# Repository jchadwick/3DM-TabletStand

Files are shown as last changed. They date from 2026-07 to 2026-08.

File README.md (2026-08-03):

# 3DM Tablet Stand

A 3D-printable, pedestal-mounted holder for a 2024 onn. 8-inch tablet. The holder is intended to slide onto an existing vertical 32 mm OD tube and present the tablet in landscape orientation at a kiosk-like 10 degrees back from vertical (80 degrees above horizontal).

The source tablet mesh and visual references are preserved under [`reference/`](reference/). The always-loaded project rules are in [`AGENTS.md`](AGENTS.md); the active specification, decision history, and validation workflow are indexed in [`docs/`](docs/README.md). The active support-minimized design is generated under [`build/v2/`](build/v2/). Superseded V1 remains available only through Git history at commit `560c6e8`.

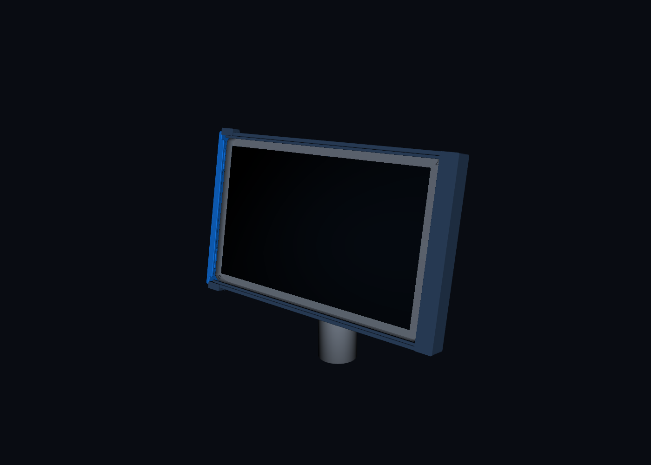
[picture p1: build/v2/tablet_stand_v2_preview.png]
Version 2 tablet stand preview


## Locked design inputs

- Tablet envelope from the supplied OBJ: **200 x 123 x 8.4 mm**.
- Landscape orientation; USB-C is centered on the right short edge as viewed from the screen side.
- Existing support: **32 mm OD vertical tube**.
- Proven printed fit: **32.2 mm ID closed sleeve**, installed by sliding the holder down over the tube end.
- Screen angle: **10 degrees back from vertical / 80 degrees above horizontal**, with the near/bottom edge lower and the far/top edge higher and farther from the user.
- Styling: simple and sleek, with sturdy support but minimal enclosure.
- Retention direction: slide-in edge rails with a screw-free left stop that slides down in a continuous captured dovetail. The groove has a closed internal bottom, with no projecting nub, hook, or detent bump.
- Cable: a slim plug protrudes 0.256 in (6.50 mm) from the tablet; its flat cable section is 0.6 mm thick for roughly 2 in before transitioning to confirmed 3.45 mm round braided cable.
- USB-C handling: the right-angle pigtail turns immediately behind the tablet; its connection and downstream cable stay largely hidden across the open back before entering an open groove/clip on the tube sleeve.

## Repository layout

```text
docs/                 Design decisions and open measurements
docs/README.md        Documentation entrypoint
docs/current-design.md Canonical active design specification
docs/decision-log.md  Chronological record of confirmed and revised decisions
cad/                  Parametric CadQuery source
scripts/              Build validation and direct CAD preview tooling
build/v2/             Active modular STEP, print STLs, parameters, and previews
reference/images/     Uploaded visual references
reference/tablet/     Supplied OBJ and material file
```

## Build the active model

The current project environment uses Python 3.12 with CadQuery 2.8.0. From an environment containing the packages in `requirements.txt`:

```bash
python cad/tablet_stand_v2.py
python scripts/validate_model_v2.py
python scripts/render_cadquery_preview_v2.py
```

## Current status

1. The active model splits the cradle, rear tilt bracket, and sleeve onto support-friendly print datums.
2. Two keyed adhesive joints assemble the main body; print the shared alignment-key STL twice.
3. All active STL files are watertight single solids and preserve the confirmed physical fit dimensions.
4. Exact-production right-side, button, and two-piece left-slide coupons verify the rails, USB-C route, concealed button groove, and screw-free stop fit.
5. Superseded V1 is intentionally absent from the working tree and remains recoverable from Git history.

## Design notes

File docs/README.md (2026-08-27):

# Documentation Guide

Use these documents in this order when resuming work:

1. [`../AGENTS.md`](../AGENTS.md) — always-loaded operating rules and fit-critical context.
2. [`current-design.md`](current-design.md) — the current, actionable specification.
3. [`assembly.md`](assembly.md) — illustrated V3 bracket, sleeve, and tablet assembly instructions.
4. [`decision-log.md`](decision-log.md) — confirmed measurements and decision history.
5. [`validation.md`](validation.md) — required build, validation, and preview checks.
6. [`architecture/decisions/`](architecture/decisions/) — accepted cross-cutting design decisions.
7. [`design-brief.md`](design-brief.md) — original conversation context, source provenance, and open questions.

The `build/v2/README.md` file describes generated artifacts only; it is not the authority for design decisions. Superseded V1 documentation remains in Git history at commit `560c6e8` and is not part of the active workflow.

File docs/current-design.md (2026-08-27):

# Current Design Specification

## Purpose and status

The project is a simple, sleek, FDM-printable landscape holder for a 2024 onn. 8-inch tablet. It mounts permanently to the accessible top end of a vertical 32 mm OD tube. V3 is the active split-cradle design: its physical tongue/receiver coupon fit, the corrected wedge retained and released successfully, and on 2026-08-27 the user reported that all production parts printed well and fit great. V3 preserves the tested tablet, button, USB-C, tube, and cable interfaces while replacing both the 215 mm-wide cradle print and separate left cap with two bed-friendly wings. Permanent adhesive assembly uses the rear tilt bracket between the fixed right wing and sleeve as illustrated in [`assembly.md`](assembly.md). Superseded V1 is archived only in Git history at commit `560c6e8` and is not maintained.

## Orientation and coordinates

The user views the tablet in landscape. The screen faces the user; the bottom long edge is lower and nearer; the top long edge is higher and farther away. The screen is **10 degrees back from vertical**, which is **80 degrees above horizontal**. Do not reintroduce the superseded nearly-flat 10-degrees-above-horizontal interpretation.

In the CadQuery model, X runs left (−) to right/USB-C side (+), Y runs user/bottom (−) to far/top (+), and Z runs up. The tablet plane is rotated +80 degrees about X.

## Fit-critical dimensions

| Feature | Value | Status |
|---|---:|---|
| Tablet envelope | 200 × 123 × 8.4 mm | Measured from supplied OBJ |
| Tablet allowance | 1.0 mm total in X/Y; 0.8 mm in Z | Restored after the zero-nominal Y/Z fit test proved too tight |
| Existing tube | 32.0 mm OD | User measurement |
| Sleeve ID | 32.2 mm | User fit-tested; preserve |
| Sleeve OD / wall | 40.2 mm / 4.0 mm | Active design value |
| Sleeve body / engagement | 50 mm / 51 mm | Active design value |
| Seating cap | 3.0 mm | Deterministic tube stop |
| Sleeve rear offset | 24 mm | Keeps tube out of tablet cavity |
| Sleeve vertical placement | Bottom level with holder's lower long edge (Z = -64.53 mm) | User-requested alignment; rear assembly lowered 14.53 mm |
| V3 center retention | One removable printed tapered cross-wedge through the lower tongue/receiver | No cradle adhesive or screw required; the same 4 × 4 mm channel accepts an M3 bolt, washers, and nut as a fallback after hardware dimensions are confirmed |
| USB-C plug projection | 6.50 mm | User measurement |
| Flat cable thickness / length | 0.6 mm / about 50.8 mm | User measurement |
| Right-angle pigtail reach | 51.4 mm | Marked on user photo; endpoint definition should be confirmed before a close fit |
| Downstream connector body | 9.6 mm marked dimension | User photo; measurement axis/meaning still to confirm |
| Round braided cable diameter | 3.45 mm | User measurement |
| USB-C plug-pocket depth | 8.0 mm clear | 6.50 mm projection plus provisional clearance |
| Rear cable opening | 16 × 12 mm (Y × X): 4 mm inboard + the original full 8 mm outboard span | Photo-requested enlargement adds the green-marked tablet-side area without filling any of the original opening; the plug chamber above remains 8 mm deep |
| Power/volume group | 20–60 mm from landscape top-left; 2 mm wide across tablet thickness; centered; 1 mm edge protrusion | User measurements |
| Top button channel | Concealed internal groove, 2 mm high × 1.2 mm deep; active V3 span X = −103.5 mm to the center seam, with 0.2 mm cutter overrun | Clears the 1 mm button projection over the complete removable left-wing slide path while preserving a solid 1.8 mm exterior rail wall, retaining perimeter, and closed left outer wall |
| Rear bracket cable clip/channel | One 12 mm-long open C-channel, X = 25–37 mm; 4.15 mm ID / 2.8 mm snap opening | Replaces two 6 mm clips; removes the inaccessible inner X = 16 mm clip while preserving total cable contact length and clearing the center gusset |
| Braided-cable sleeve channel | 4.15 mm ID / 2.8 mm snap opening | 0.70 mm total clearance around confirmed cable diameter |
| Sleeve channel embed / remaining wall | 1.2 mm / 2.8 mm minimum | Keeps the 32.2 mm tube bore intact |
| Exposed finish | Rear frame opening follows the tablet's approximately 7.0 mm plan corner radius; outer rear-frame radius is 28.0 mm. One continuous screen-facing ring now supplies all four visible rails/closures and is interrupted only by the flush 0.35 mm wing split—there are no stacked lips, end caps, bezel overlays, or coplanar shroud faces. Its opening remains 196.6 × 119.6 mm with 5.3 mm tablet-concentric corners and 1.7 mm overlap. V3 keeps 1.45 mm rail/wall, 1.05 mm lip, and 1.70 mm left-closure plan corners, with 1.30 mm front/exposed rail/wall fillets and 0.90 mm ring fillets; rear print datums remain flat | Removes visible ridges and superseded slider/end-stop remnants while preserving the approved screen edge, cavity fit, insertion path, and rear-face-down layout |
| V2 main-body split | Cradle, rear tilt bracket, sleeve | Separates conflicting print axes |
| Structural glue alignment | 35 × 15 × 1.8 mm cross key, print quantity 1 | Used only for the unchanged rear-bracket-to-sleeve bond; the bracket bonds to the fixed right wing without a cradle key, and the removable left wing receives no adhesive |
| Cradle-to-bracket bond | 74 × 36 mm nominal mating face | Align matching side and top edges |
| Bracket-to-sleeve bond | 60 × 28 mm nominal mating face | Align matching side and front edges |
| V2 left cap (historical) | Horizontal local +X insertion on two enlarged tapered rail-end plugs | Physically fit well, but the entire separate-cap scheme is superseded by the integral V3 left wing |
| V3 cradle split | Left wing 125.00 × 139.00 × 14.20 mm; right wing 111.33 × 139.00 × 14.20 mm | Replaces the 215 mm-wide single cradle print; the one-piece front ring and buried rear shrouds absorb the outer joiner blocks without visible ridges; both wings remain rear-face-down and fit comfortably on the 220 mm bed |
| V3 removable joint | Three integral +X tongues: one at each long rail and one through the center plate; 18 mm seated insertion | Physical coupon fit despite major adhesion/stringing defects; retain the matching receiver's 0.50 mm total root and 1.10 mm total tip/lead clearances |
| V3 locking wedge | One corrected printed 3.70-to-3.30 mm tapered cross-wedge with a 7 mm pull head | Corrected pin retained and released successfully in the physical coupon; original floating-body G-code is stale; channel can take an M3 bolt if necessary |
| V3 left edge | Fully enclosed, rounded, integral part of the left cradle wing | No separate cap, plugs, sockets, screw, or nub; the left wing itself closes the holder during two-piece tablet assembly |
| Right fit coupon | Exact X = 78.0–111.5 mm crop of V2 cradle | 33.5 × 130 mm plan envelope; tests restored rail fit, right-edge seating, USB-C pocket, and open 16 × 8 mm cable rectangle |
| Button fit coupon | Exact top-left production-rail crop | 73.5 × 11 × 14.8 mm envelope; tests insertion path, seated button clearance, and intact wall after relief |
| Twin-plug coupon (historical) | Exact V2 crops of one rail socket and its identical tapered plug | Physically passed and remains useful process evidence; the joint is absent from V3 |

## Functional design

- The V3 candidate is assembled from two flat-print cradle wings, one removable locking wedge, a rear tilt bracket, and a closed sleeve. There is no separate left end cap and no cradle adhesive. The structural alignment-key STL is printed once for the unchanged bracket-to-sleeve glue joint.
- The left wing has a continuous rounded wall with no separate cap or visible entry step. The obsolete 4 mm V2 end-stop rail lead is closed; each long rail overlaps the integral closure by 0.20 mm behind the visible face. One screen-facing ring spans the complete 139 mm envelope and both wings, leaving only the flush center split. The right wing retains the tested USB-C housing. Its rear-floor opening keeps the complete original 8 mm outboard span and adds 4 mm inboard: the 16 × 12 mm opening runs from X = 96.5–108.5 mm across the fitted tablet edge at X = 100.5 mm. All V2 cap-specific tapered plugs, sockets, receiver bulges, lip overlays, and slider-looking remnants are absent from V3.
- To load the tablet, seat its USB-C/right edge in the fixed right wing, align the fully enclosed left wing, and slide it +X until all three tongues reach their closed socket seats. Push the tapered wedge through the lower transverse channel. To service the tablet, pull the wedge and slide the left wing back off.
- The two outer tongues are 6 mm tall, bed-supported blocks entering locally reinforced receivers with open bed-side floors and softened exterior edges. Their 4.5 mm maximum socket roofs stay below the confirmed 10 mm PLA bridge rule. The center tongue remains within the 3 mm rear plate and enters a through-depth planar pocket.
- The lower tongue and receiver share a 4 × 4 mm transverse channel. The printed wedge narrows from 3.70 to 3.30 mm for a forgiving lead and snug seated root. If the actual PLA wedge is unreliable, the channel clears an M3 shaft; exact head, washer, nut, and length still require the user's hardware measurements.
- The rear bracket is bonded only to the fixed right wing and the bracket-to-sleeve joint remains glued. The bracket may contact the removable left wing but must receive no adhesive there. This preserves tablet serviceability while the existing 74 × 36 mm plate helps resist out-of-plane movement at the seam.
- The cradle prints with its complete rear frame datum on the bed. The cable clip/channel is on the rear bracket. The previous end-stop screw boss and pilot are removed.
- The rear bracket's 74 × 36 mm tilted plate bonds to the matching upper region of the cradle center plate. The active V3 production STL prints on that broad bond plate with its open cable channel facing upward; this supersedes the old V2 foot-down production orientation for the replacement bracket.
- The sleeve prints upside down on a 60 × 46 mm flange. Its tube-entry bore therefore remains open upward and its 3 mm seating cap becomes a supported floor rather than a 32.2 mm bridge.
- The rear bracket bonds only to the right cradle wing, using its existing broad face without a cradle alignment key. The bracket-to-sleeve bond retains one loose-fit 35 × 15 × 1.8 mm cross key and the previously validated groove clearance. Adhesive must be selected and prepared for the actual filament, but no adhesive belongs on the removable left wing or tongue/socket joint.
- The holder slides down over the tube using the unchanged closed cylindrical sleeve with a solid seating cap.
- The complete rear sleeve/collet assembly is lowered so its bottom is level with the installed holder's lower long edge. The sleeve dimensions and proven tube fit are unchanged.
- Two rear gussets connect the rear-offset sleeve to the tablet back support.
- The tablet is loaded between the two cradle wings before the wedge is inserted. The integral left wing closes the left edge; no separate cap is printed or installed, and the wing remains removable.
- The landscape-top rail has a concealed 2 mm-high × 1.2 mm-deep groove in its inner face, centered on the tablet's thickness. In active V3 it runs continuously from the integral closure-side rail interior at X = −103.5 mm to the center seam, with only a 0.20 mm cutter overrun past the split for a clean edge. This clears the buttons during the entire +X left-wing slide, not only at their seated position. The groove does not cut the left outer closure or exterior face: a solid 1.8 mm outer wall and the complete screen-facing ring remain.
- The single continuous screen-facing ring covers the right side from the tablet edge to the solid outer wall; two internal stop walls beneath it locate the tablet while accommodating the 6.50 mm-projecting USB-C plug. The ring remains structurally continuous because the cable opening is in the rear pocket floor, not through the visible face.
- The right-angle adapter turns immediately around the tablet's right edge and onto the open back; the flat pigtail and its downstream connection should be largely hidden behind the tablet rather than leaving straight out through the right wall.
- The right side presents a continuous enclosed screen-facing face: the outer wall and full-depth cap span the complete 139 mm V3 perimeter, including the extended top/bottom corners. The plug chamber remains open toward the tablet cavity and keeps its full 8 mm depth above the rear floor for the recorded 6.50 mm projection. The rear-floor opening is enlarged from its original 16 × 8 mm area by adding the green-marked 4 mm inboard relief, producing a 16 × 12 mm opening. None of the original outboard opening is filled or removed.
- The 3.45 mm braided section snaps into one 12 mm-long open C-channel on the rear bracket. The channel spans X = 25–37 mm in the former outer-clip region; the crowded inner X = 16 mm clip is removed. From the channel it drops through open space outside the right gusset, sweeps behind the sleeve, and enters the rear-facing external sleeve channel through its snap opening. No segment passes through a holder, gusset, or sleeve solid, and the 9.6 mm-marked connector body remains accessible outside all captive features.
- The external sleeve channel has 4.15 mm internal clearance and a 2.8 mm snap opening. Its shallow 1.2 mm embed leaves at least 2.8 mm of the original 4 mm sleeve wall and does not intersect the tested 32.2 mm bore.
- The rear frame opening follows the supplied tablet mesh's approximately 7 mm corner curve, and the outer rear-frame plan radius remains 28 mm. The visible front is now authored as one asymmetric ring rather than a union of separately pre-filleted V2 lips, left/right caps, corner infills, and full-height shrouds. It keeps the established 1.70 mm outer short-edge plan corner and 0.90 mm cross-sectional fillet while cutting the same sharp-edged 196.6 × 119.6 mm opening with 5.3 mm corners and 1.7 mm tablet overlap. The 1.30 mm long-wall and short-wall finish remains on exposed/front edges; the rear-side wall edges stay flat where required for a complete watertight print datum. Two rear shrouds stop 0.70 mm below the front face and fuse inside the ring, hiding joiner blocks without a coplanar ridge. The left and right wing colors meet only at the unavoidable 0.35 mm center split, and V3 has no end-stop, slider, cap, or screw-era surface remnant.
- Keep the rear open for material efficiency, airflow, and access. Do not convert this to a full bezel without confirming all device clearance zones.
- Active shared geometry is in `cad/tablet_stand_core.py`; the tested unsplit geometry remains in `cad/tablet_stand_v2.py`, and `cad/tablet_stand_v3.py` owns the removable tongue/wedge split, V3 assembly, and exports. Generated V3 review outputs are under `build/v3/`. If the V3 physical joint coupon passes, promote V3 to the sole production path and archive the V2-only workflow rather than maintaining both indefinitely.
- Before another full right wing, print or otherwise physically verify the revised right-side USB region rear-face down in the intended PLA process. Slide the tablet's right edge through the production rails, seat it against the internal stops, connect the real USB-C adapter, and confirm that the complete thick cable section turns through the enlarged 16 × 12 mm rear rectangle without pinching or forcing the tablet. The prior physical wing proves tablet fit, not this enlarged floor opening.
- Also print `tablet_stand_v2_button_fit_coupon.stl` rear-face down. Slide it along the tablet's landscape-top edge from the left and confirm that the button group passes freely through the concealed inner groove without being pressed, while the outside of the rail remains closed and smooth.
- The first `tablet_stand_v3_lock_coupon_all3.stl` print physically passed tongue/receiver fit despite severe adhesion and stringing. The corrected pin then retained and released successfully. Do not rescale or change the confirmed tongue/socket clearances. The stale combined coupon G-code and pre-finish right-wing slices remain recoverable from Git history. The prior right-wing production job used snug 45° supports and a 5 mm brim and completed on 2026-08-10; on 2026-08-27 the user reported that all current production parts printed well and fit great.

## Current print status

- The replacement rear bracket uses one 12 mm outer cable channel and the active V3 broad-plate-down, channel-up orientation. Its functional PLA slice uses 0.20 mm layers, five walls, 40% grid infill, no supports, and no brim; validation passed at 7.5 mm³/s peak flow with an estimated 1 h 31 m / 22.4 g.
- The user explicitly authorized the print. A fresh full-bed camera snapshot showed an empty plate, and Moonraker accepted the job at 2026-08-27 04:48:05 UTC. Completion and physical cable insertion remain to be confirmed.

## Full-cradle slice status

- The unsplit V2 cradle is 215 × 135.6 × 14.8 mm and technically fits the confirmed 220 × 220 mm bed, but its narrow margin motivated the V3 split.
- The V3 left and right cradle-wing STLs are each single watertight solids and remain rear-face-down. Their largest plan dimension is 139 mm, leaving generous bed margin.
- Previous full-cradle, end-stop, and combined V3 coupon G-code files are stale for the current geometry; Git history retains them as process evidence. The tongue/receiver fit and wedge retention gates passed. The corrected full-span right-wing job completed from prior geometry using rear-face-down, 0.16 mm layers, 3 walls, 20% grid infill, 55° snug build-plate-only supports, a 0.24 mm Z gap, 0.70 mm XY gap, 3 interface layers, and a 5 mm brim. That print was very stringy, but the tablet slid in smoothly and fit snugly. On 2026-08-27 the user subsequently confirmed that all current production parts printed well and fit great. Preserve the active cavity and joint dimensions for any reprint.

## Known unknowns before a full print

- Flat cable and connector-body width.
- Whether the photo's 9.6 mm annotation is connector width, height, or another measurement.
- Speaker, camera, microphone, and any other edge clearances not covered by the measured power/volume group.
- The successful V2 twin-plug coupon remains useful PLA fit evidence, but it does not replace the required V3 tongue/wedge coupon test.
- Unobstructed tube length above its existing mounting point.
- The Ender-3 Pro profile, 0.4 mm nozzle, PLA, 220 × 220 × 250 mm build volume, and rear-face-down cradle orientation are verified. The tongue/receiver physically fit on 2026-08-10 despite major adhesion/stringing defects, and the corrected wedge retained and released successfully. Full production slices and first-layer adhesion strategy remain to be reviewed.
- Adhesive selection, surface preparation, clamp method, and cure time for the selected filament.

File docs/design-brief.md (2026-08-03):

# Tablet Stand Design Brief

## Goal

Create a simple, sleek, sturdy FDM-printable holder for a 2024 onn. 8-inch tablet. The assembly will live permanently on top of a vertical 32 mm OD tube. The tablet should be securely retained without a bulky enclosure or unnecessary obstruction of its surfaces.

## Supplied references

- `reference/tablet/tinker.obj`: Tinkercad export of the tablet, with a measured axis-aligned envelope of 200 x 123 x 8.4 mm.
- `reference/tablet/obj.mtl`: material definition accompanying the tablet OBJ.
- `reference/images/slim-usb-c-cable.png`: visual reference for the low-profile USB-C lead.
- `reference/images/tilt-reference.png`: an early side-view sketch retained as source history; its 10-degrees-above-horizontal interpretation is superseded by the kiosk-angle correction below.

Source file SHA-256 checksums:

```text
2c9b8806e64e52a87e7ebacec791b912b9a4fb774c618ab4b1893b57f28cefe8  tinker.obj
fcf8ac13a37b9b38b3052e32e8f2407ed103fb5f62b3468fe42578f922007f8b  obj.mtl
575f7f808ad992e87ae410be5e9742a2c2b65725099cb73130cf4a423226180e  slim-usb-c-cable.png
de3a6b13c21a19f52a0c6697288e47ec1d9f3da20c9b4bcc9ad1b73e86abc622  tilt-reference.png
```

## Geometry and orientation

- Tablet nominal envelope: 200 mm wide, 123 mm deep, and 8.4 mm thick.
- The tablet is landscape when seen by the user.
- The bottom long edge is closest to the user and lower.
- The top long edge is farther from the user and higher.
- The screen plane is **10 degrees back from vertical**, equivalently **80 degrees above horizontal**, and faces the user like a kiosk.
- The top long edge is farther from the user and higher; the bottom long edge is nearer and lower.
- Across the 123 mm tablet depth, an 80-degree rise produces approximately 121.1 mm of vertical elevation and 21.4 mm of horizontal setback between the long edges.
- The USB-C connection is at the midpoint of the right 123 mm edge when viewed from the screen side.

## Pedestal interface

- The existing tube is vertical with a 32 mm outside diameter.
- A previously test-printed cylinder with a 32.2 mm inside diameter fits the tube tightly; preserve that functional ID.
- The stand should use a closed sleeve and install by sliding straight down over the accessible tube end.
- Because the tablet is nearly vertical, the sleeve must sit behind the screen plane rather than intersecting it. Version 1 offsets the sleeve axis 24 mm behind the tablet plane and ties it to the central back support with two ribs.

## Tablet support and retention

Concepts considered:

- **Open gravity tray:** easiest to print and least obstructive, but not secure enough against bumps or lifting.
- **Flexible snap clips:** compact and removable, but rejected because stronger retention is wanted and the printer/filament do not produce consistently tight tolerances.
- **Full screw-together bezel:** very secure, but uses more material, obstructs more of the tablet, and requires detailed cutouts for buttons, speakers, cameras, and screen margins.
- **Selected direction — slide-in rails with one-screw end stop:** narrow fixed rails overlap only the tablet's outer bezel. The tablet slides into a deliberately forgiving channel, and a removable stop secured by one M3 screw blocks the insertion edge. Soft foam or felt can remove rattle and protect the tablet without relying on a precision printed fit.

The selected direction should keep the rear largely open for airflow and material efficiency. Edge rails and the end stop must avoid the USB-C connection and should not cover unknown button, camera, or speaker locations until those locations are verified.

## USB-C routing

- Port location: center of the tablet's right short edge.
- Flat cable section: 0.6 mm thick for approximately 2 in (50.8 mm).
- Plug projection from tablet: 0.256 in (6.50 mm).
- The original width value remains ambiguous, so the first design should use a generous plug chamber and cable groove rather than a close-fitting captive tunnel.
- The right-angle adapter turns immediately behind the tablet. Its photo-marked 51.4 mm pigtail and downstream connection should stay behind the open back, then route to an open groove/clip on the sleeve or collet before exiting near the tube.
- The downstream cable is confirmed as 3.45 mm diameter round braided wire. Version 1 gives it a 4.15 mm open snap channel on the rear of the sleeve and preserves at least 2.8 mm of sleeve wall over the tested bore.
- Any turn in the cable route should be broad and radiused. The printed holder must not clamp the thin flat section, force a sharp bend at the connector, require the larger downstream connector to pass through a captive tunnel, or cut into the tested 32.2 mm sleeve bore.

## First concept intent

- A lightweight skeletal back support with narrow perimeter rails.
- A removable end stop retained by one M3 screw.
- A vertical 32.2 mm ID sleeve centered left-to-right and offset behind the tablet plane.
- Low-profile gussets blending the sleeve into the back support.
- A right-edge USB-C pocket that lets the right-angle pigtail turn behind the tablet, plus a largely hidden and serviceable rear route to the tube sleeve.
- Rounded exterior edges and a visually quiet, symmetric form except where the cable route requires asymmetry.

## Measurements to validate before final print

- Flat cable and connector body width.
- The meaning/axis of the photo-marked 9.6 mm connector dimension.
- Exact locations of power/volume buttons, speakers, cameras, and microphones near any retaining rail.
- Desired sleeve engagement length and available unobstructed tube length.
- M3 screw length and whether a nut, heat-set insert, or tapped plastic hole will be used.
- Printer nozzle, layer height, build volume, filament type, and preferred print orientation.
- Fit allowance around the tablet, ideally checked with a small rail-and-stop test coupon before printing the full holder.

## Version 1 implementation

The first parametric concept, now archived at Git commit `560c6e8`, used a 1.0 mm total allowance in X and Y and 0.8 mm in Z, narrow U-shaped rails on the near and far long edges, internal right corner stops behind a closed USB-C plug housing, and a full-height removable left end stop with an M3 clearance hole. Its measurements that survived physical testing were promoted into the active V2 core; the superseded model itself is not maintained.

With the corrected kiosk orientation and closed cable end, the installed main-body envelope is approximately 216.0 x 66.42 x 130.49 mm. Both exported STL parts are single watertight solids. Version 1 is a form and fit concept—not yet a production-ready print—and should be revised after checking the physical tablet's controls and testing a small fit coupon.

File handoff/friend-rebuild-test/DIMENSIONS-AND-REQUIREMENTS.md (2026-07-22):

# Dimensions and requirements

This sheet consolidates only the user's words, measurements, and supplied reference assets. It does not use or describe the existing stand CAD.

## Tablet

| Item | Value / requirement | Basis |
|---|---:|---|
| Device | 2024 onn. 8-inch tablet | User prompt |
| Supplied reference envelope | 200 × 123 × 8.4 mm | Direct min/max measurement of vertices in `assets/tinker.obj` |
| Intended orientation | Landscape | Right-hand short-edge USB-C placement and supplied tablet envelope |
| USB-C location | Center of the right-hand side/short edge when facing the screen | User prompt |
| Final screen angle | 10° back from vertical; equivalently 80° above horizontal | Later user correction; supersedes the early 10°-above-horizontal interpretation |
| Direction of lean | Bottom long edge is closer to the user; top long edge is farther from the user | User clarification |

The OBJ is a device envelope/reference mesh, not a printable stand design. Its raw bounds are X = −93 to 107 mm, Y = −72 to 51 mm, and Z = 0 to 8.4 mm.

## Existing support tube

| Item | Value / requirement | Basis |
|---|---:|---|
| Tube outside diameter | 32.0 mm OD | User measurement |
| Tested mating bore | 32.2 mm ID | User fit test; described as perfectly tight |
| Mounting concept | Stand sits permanently on top of the tube | User prompt |

Do not substitute a generic fit allowance for the 32.2 mm bore without discussing it: that dimension comes from a physical test print on the actual tube.

## USB-C cable and adapter

| Item | Value / requirement | Confidence / note |
|---|---:|---|
| Plug/adapter projection from tablet | 0.256 in = 6.5024 mm | Later prompt explicitly uses an inch mark. The first prompt says `0.256mm`, which conflicts and appears to be a unit typo. Preserve the discrepancy until physically checked. |
| Flat section description | Flat, very low profile | Explicit user description |
| Flat-section transverse measurement | First prompt says `.7mm wide`; prior planning also treated the flat section as about 0.6 mm thick | Measurement axis and exact value should be rechecked before making a close fit |
| Annotated flat pigtail length | 51.4 mm | Handwritten marking in `assets/IMG_7233 Large.jpeg` |
| Annotated downstream connector-body measurement | 9.6 mm | Handwritten marking in the physical photo; the measurement axis is not unambiguous |
| Additional handwritten mark | `2` near the downstream connector body | Units and axis are not sufficiently clear to use as a captive-feature dimension |
| Cable after pictured pigtail | 3.45 mm diameter, round braided wire | Explicit later user measurement |

Cable routing requirements:

- The right-angle USB-C adapter turns immediately behind the tablet.
- The adapter/pigtail should be largely hidden and routed toward a groove in or on the tube collet/sleeve area.
- The tablet should be able to slide into the holder. It is acceptable to plug in the cable first and then slide the tablet into place.
- Keep cable routing open or snap-in. Both ends have USB-C connectors, so do not require a connector to pass through a small captive hole.
- Clips are acceptable and desired; the free cable path must not pass through solid material to reach them.
- The downstream connector body should remain outside close-fitting captive features until its 9.6 mm annotation axis and other body dimensions are confirmed.

## Holder behavior and appearance

- Simple and sleek.
- Sturdy, but do not enclose or “suffocate” the tablet unnecessarily.
- A front bezel is optional; a stable tray or partial wrap is acceptable.
- Retention should be more secure than an occasional snap-out arrangement.
- Outside corners should be lightly rounded/filleted so they are not sharp.
- The right side should be solid and fully enclosed in the front/oblique view, not partially exposing the tablet edge or recessed USB-C pocket; it must still accommodate the USB-C connection and rearward cable turn while supporting slide-in tablet installation.

## Measurements still needed before a close-fitting final design

- Confirm the flat cable's width and thickness axes; reconcile 0.7 mm versus approximately 0.6 mm.
- Confirm the 9.6 mm and `2` markings on the downstream connector body, including axis and units.
- Confirm tablet button, speaker, camera, and microphone locations relative to any rail, bezel, or stop.
- Confirm available tube engagement length.
- Confirm printer, nozzle, material, build volume, and intended print orientation.

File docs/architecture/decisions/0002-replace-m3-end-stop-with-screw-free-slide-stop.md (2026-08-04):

# ADR-0002: Replace M3 end stop with screw-free slide stop

- Status: superseded
- Date: 2026-08-02
- Deciders: Project maintainers
- Supersedes: ADR-0001
- Superseded by: ADR-0003

## Context

ADR-0001 established the support-minimized four-module V2 layout but retained
one M3 screw for the removable left tablet stop. The user rejected that visible
fastener and requested a left edge that installs by sliding downward and remains
removable through a guided fit or optionally permanent with a small amount of
adhesive. After reviewing the first screw-free implementation, the user also
rejected its projecting landing nub, rear hooks, and detent bumps in favor of a
sleek tongue-and-groove joint. The stop must still print separately,
must not collide with either long rail during insertion, and must preserve the
cradle's broad rear print datum. The user also requested softer exposed edges.

## Decision

Retain ADR-0001's cradle, rear-bracket, sleeve, alignment-key, and print-layout
decisions, but replace the M3-mounted end stop with a screw-free top-down slide
stop. Use one continuous captured dovetail: the production cradle receives a
closed-bottom groove and the separate stop receives a matching undersized tongue.
The narrow groove mouth captures the wider tongue head; the internal closed
bottom establishes the seated position. Do not add rear hooks, detent bumps, or
an external lower landing. Adhesive is optional.

Use an exact two-piece production crop to physically test the slide clearance,
dovetail capture, and closed-bottom seating before the revised full cradle is printed.
Soften exposed perimeter, rail, lip, and stop edges with the active fillet radii
without changing the confirmed tablet-cavity allowances.

## Consequences

### Positive

- Eliminates the only visible mechanical fastener and its unconfirmed screw
  length and pilot strategy.
- The stop remains independently replaceable and can be glued only if desired.
- The closed-bottom groove gives a deterministic seated position while the
  dovetail prevents the stop from peeling away from the cradle.
- Removing the external landing, hooks, and bumps restores a clean rounded
  lower-left silhouette and the cradle's 215 × 130 mm envelope.
- Rounded longitudinal edges make the printed holder less sharp in hand.

### Negative

- The friction fit is printer- and material-dependent and requires a physical
  PLA coupon before the full cradle.
- The long, enclosed sliding surfaces remain sensitive to printed PLA clearance
  and must be physically tested before committing to the full cradle.

## Alternatives considered

### Retain the local-Z M3 screw

Rejected because the user does not want a visible screw or mechanical fastener
on the tablet edge.

### Use separate snap hooks, detents, and a lower landing

Initially implemented, then rejected because the small features and projecting
nub looked vestigial and bulky compared with the requested clean tongue-and-groove
joint.

### Glue the stop permanently with no guides

Rejected because it would make alignment less repeatable and remove the option
to replace or service the tablet without breaking a bond.

## Verification

- `.venv/bin/python cad/tablet_stand_v2.py`
- `.venv/bin/python scripts/validate_model_v2.py`
- `.venv/bin/python scripts/render_cadquery_preview_v2.py`
- Validation samples the complete insertion travel and requires zero solid
  intersection at every sampled offset.
- `build/v2/tablet_stand_v2_left_stop_multiview.png` shows the seated, sliding,
  and transverse dovetail-profile views.
- `tablet_stand_v2_left_slide_coupon_cradle.stl` and
  `tablet_stand_v2_left_slide_coupon_stop.stl` are watertight exact crops for
  the required physical fit test.

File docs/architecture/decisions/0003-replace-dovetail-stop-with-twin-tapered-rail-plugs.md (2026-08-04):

# ADR-0003: Replace dovetail stop with twin tapered rail plugs

- Status: accepted
- Date: 2026-08-04
- Deciders: Project maintainers
- Supersedes: ADR-0002
- Superseded by: None

## Context

ADR-0002 replaced the visible M3 fastener with a top-down captured dovetail. The
physical coupon could not be cleaned successfully: support was trapped in the
tight groove, while an unsupported attempt collapsed and strung badly with the
user's dry but difficult PLA. The left cap still needs positive alignment and
friction retention without screws, brittle snap hooks, or inaccessible support.

## Decision

Replace the dovetail with two horizontally inserted tapered plugs, one aligned
with each long-edge rail. Each plug has a support-free house profile and tapers
from 2.15 × 2.95 mm at its root to 1.80 × 2.60 mm at its tip over 12 mm. It
enters a matching 2.40 × 3.20 mm open-ended socket with a 45-degree roof and a
closed seating end, providing 0.25 mm total root clearance and 0.60 mm total tip
clearance. Reinforce both rail ends and add 45-degree underside ramps. Preserve
the measured concealed button groove, rounded screw-free silhouette, and
optional adhesive strategy.

Print the socket and plug coupons as two separate, support-free jobs before
re-slicing the complete cradle and cap.

## Consequences

### Positive

- Removes all support from the fit surfaces and leaves both socket mouths open
  for inspection and cleanup.
- Uses two rail-aligned contacts to resist cap rotation while preserving the
  clean rounded edge and screw-free assembly.
- Tapered lead-in reduces sensitivity to the user's string-prone PLA while the
  socket backs provide deterministic seating.

### Negative

- The cradle becomes 3.6 mm wider across Y because of the two subtle receiver
  reinforcements.
- Friction remains process-dependent and requires a physical coupon before the
  long cradle print.
- The full cradle and cap G-code must be regenerated after the coupon passes.

## Alternatives considered

### Retain the supported dovetail

Rejected because the physical coupon showed that support could not be removed
reliably from the narrow captured groove.

### Use snap hooks or detents

Rejected because the user requested a sleek joint without exposed catches, and
small PLA hooks would be brittle and printing-sensitive.

### Use magnets or other hardware

Rejected because the requested closure should not require mechanical hardware.

### Glue the cap with no alignment features

Rejected because it would make placement less repeatable and make service or
replacement more destructive. The twin plugs align the cap whether or not the
user later chooses a drop of glue.

## Verification

- `.venv/bin/python cad/tablet_stand_v2.py`
- `.venv/bin/python scripts/validate_model_v2.py`
- `CAD_PREVIEW_HEADLESS=1 .venv/bin/python scripts/render_cadquery_preview_v2.py`
- Validation samples horizontal insertion at six positions, checks zero
  collision, verifies both seating ends and receiver walls, and requires
  watertight production and coupon exports.
- `build/v2/tablet_stand_v2_left_stop_multiview.png` shows seated, exploded,
  and socket-section views.
- The two individual coupon G-code jobs validate without supports or slicer
  stability warnings; a physical fit test remains required.

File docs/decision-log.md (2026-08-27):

# Project Decision Log

### One accessible rear cable channel and clips-up bracket reprint — 2026-08-27

- The user reported that the inner rear cable clip butted against the center support and lacked enough clearance to be useful. Removed that X = 16 mm clip.
- Replaced the two 6 mm clips with one continuous 12 mm open C-channel in the former outer-clip region. It spans X = 25–37 mm, keeps its outer edge flush with the 74 mm bracket plate, preserves the same total cable contact length, and leaves 10 mm clearance to the right gusset.
- The active V3 rear-bracket STL now prints on its broad 74 × 36 mm cradle-bond plate with the cable-channel opening facing upward. This supersedes the V2-derived foot-down orientation for this replacement print; installed geometry and both adhesive mating faces are unchanged.
- The channel retains the confirmed 4.15 mm internal diameter and 2.8 mm snap opening for the measured 3.45 mm braided cable. The downstream open-space route and sleeve channel remain unchanged.
- The replacement bracket was sliced in its new broad-plate-down orientation using functional PLA settings: 0.20 mm layers, five walls, 40% grid infill, no supports, and no brim. Validation passed at 7.5 mm³/s peak flow, 86 × 48 × 28.6 mm toolpath bounds, about 22.4 g filament, and 1 h 31 m estimated time.
- The user explicitly authorized the print. The printer was reachable and ready, and a fresh camera snapshot clearly showed the complete build plate empty. Moonraker accepted `tablet_stand_v3_rear_bracket_clips_up_pla.gcode` at 2026-08-27 04:48:05 UTC; the follow-up status reported the job printing.

### Production parts fit and illustrated adhesive assembly — 2026-08-27

- The user reported that all current V3 production parts printed well and fit great. This supersedes the earlier status that the left wing and remaining modules were unprinted or unauthorized; preserve the active tablet allowance and tongue/socket/wedge dimensions.
- Clarified that the cradle does not attach directly to the sleeve. The rear tilt bracket provides two permanent adhesive joints: its angled plate bonds only to the fixed USB-C/right wing, and its horizontal foot bonds to the sleeve flange.
- The V3 cradle-to-bracket bond is intentionally unkeyed. The reused bracket retains its historical `+` recess, but the fixed right wing has no matching groove and receives no key; only the right-half broad-face overlap is glued.
- Added direct-CadQuery annotated renders and `docs/assembly.md`. The single printed 35 × 15 × 1.8 mm cross-key is used only between the matching recesses on the underside of the bracket foot and top of the sleeve flange. The key is deliberately loose for alignment; adhesive over the broad mating faces carries the joint.
- No adhesive belongs on the removable left wing, tablet, tongues, receivers, wedge, sleeve bore, or cable channel.

### Unified smooth V3 front perimeter and full-travel button groove — 2026-08-26

- The user identified visible ridges/double outlines along the screen-facing top and bottom rails and a disjointed left edge that still read like the superseded separate end-stop/slider. Those artifacts came from stacking independently pre-filleted V2 long lips, separate left/right caps, a corner bezel, and full-height receiver shrouds on coplanar faces.
- Replaced those visible pieces with **one continuous 2.0 mm screen-facing CadQuery ring** spanning the actual left closure, both long rails, and the right USB-C closure. The ring is cut once by the approved **196.6 × 119.6 mm opening with 5.3 mm corners and 1.7 mm overlap**, then divided only by the required **0.35 mm center wing seam**. There are no separate cap, lip overlay, bezel overlay, or coplanar shroud faces left on the visible front.
- Closed the obsolete V2 **4.0 mm left rail entry lead** in active V3. Both long rails now run into the integral left closure with a hidden **0.20 mm overlap**, removing the slider-looking step while preserving the removable two-wing +X insertion and the unchanged **125.00 × 139.00 × 14.20 mm / 111.33 × 139.00 × 14.20 mm** wing envelopes.
- Extended the concealed inner button groove to the complete removable left-wing travel: **2.0 mm high × 1.2 mm deep from X = −103.5 mm to the center seam**, with a 0.20 mm cutter overrun. The integral left outer wall, screen-facing ring, and **1.8 mm exterior rail wall** remain solid, so the tablet buttons cannot catch while the left wing slides +X.
- Rear receiver shrouds now stop 0.70 mm below the visible face and fuse inside the ring rather than ending coplanar with it. Their screen-side edges retain the approved **1.30 mm** wall treatment, the ring retains **0.90 mm** fillets, and rear mating/print datums stay flat. This small rear-edge construction adjustment eliminates tangent duplicate mesh faces; all production and coupon STLs validate watertight.
- V2 defaults and historical fit coupons are unchanged. CAD validation confirms one connected planar front face, continuous rail samples on both wings, the complete button-channel path and bounded height/depth, unchanged tablet/USB/joint interfaces, collision-free insertion, rear-face-down datums, and 220 mm bed fit. Direct front, oblique, left-edge, rear, button-channel, joint, and print-layout renders show a flush perimeter with only the center seam. This quality pass is not physically tested, and all prior right-wing G-code remains stale.

### Remove expired generated print artifacts — 2026-08-25

- Removed stale V3 combined-coupon and right-wing G-code, including the two obsolete right-wing INI files and the superseded rounded-finish slice's print record and validation text. The associated printed-fit decisions, coupon STLs, toolpath image, geometry/brief JSON, current production STLs, STEP, and previews remain in the active tree; deleted slices remain recoverable from Git history.
- Removed V2 G-code that no longer matches the active artifact purpose: the old two-key job, pre-current button coupon, and pre-enlargement right-fit coupon. The current V2 STLs/previews and physical fit evidence remain available.
- Conservatively retained the V2 rear-bracket G-code because the bracket geometry is still reused by V3, plus the two V2 twin-plug coupon jobs because they directly correspond to the recorded physical clearance test. They are historical/ambiguous artifacts, not authorization to print.

### Continuous pronounced V3 exterior edge rounding — 2026-08-25

- The user requested much stronger rounding around the complete outside frame, not merely larger plan-view corner curves. V3 now uses **1.30 mm cross-sectional edge fillets** continuously on the 3.0 mm rear perimeter, long rail walls, and both full-span outer end walls. This nearly full-round treatment leaves a deliberate **0.40 mm central land** rather than a knife edge.
- The 2.0 mm screen-facing lips and outer caps use **0.90 mm edge fillets**, leaving a **0.20 mm central land**. The separately cut **196.6 × 119.6 mm** screen opening remains sharp at its approved **1.7 mm overlap**, so the finish does not uncover the tablet corners or narrow the tested insertion cavity.
- The V3-only finish preserves the existing 28.0 mm outer and 7.0 mm rear-opening plan radii, 1.45 mm rail/wall and 1.05 mm lip plan corners, 1.70 mm left-closure plan corner, center split alignment, rear print datums, USB/button/cable interfaces, and all tongue/socket/wedge geometry. Historical V2 retains its tested 0.70/0.60 mm edge-fillet defaults.
- CAD validation samples the relieved and solid sides of the new fillets on all four long-rail segments and both short walls, confirms flat rear-datum material and the sharp screen-opening transition, and rechecks watertight exports and unchanged wing envelopes. The finish is CAD-validated but not physically printed; all prior right-wing G-code is stale.

### USB rear-floor enlargement clarification — 2026-08-25

- The user explicitly clarified that the green rectangle is an **addition to the original hole**, not a relocation of it. The immediately preceding 4 mm-shift interpretation was incorrect and is superseded without rewriting its Git history.
- Retained the complete original **16 × 8 mm (Y × X)** rear-floor opening from the fitted tablet edge at **X = 100.5 mm** through the plug-pocket floor to **X = 108.5 mm**, then added the green-marked **4.0 mm** inboard relief from **X = 96.5–100.5 mm**. The active opening is therefore **16 × 12 mm**, spanning **X = 96.5–108.5 mm**.
- The correction still changes only the rear floor. The USB-C port center, **8.0 mm clear plug chamber above the floor**, recorded **6.50 mm plug projection**, 3.0 mm solid outer wall, continuous screen-facing cap, tablet cavity allowances, cable clips, and downstream sleeve route remain unchanged.
- CAD validation now explicitly samples both the new 4 mm inboard relief and the retained original 8 mm outboard opening. The enlarged opening is not yet physically tested, and every earlier right-wing G-code remains stale.

### USB rear-floor opening shifted inboard after right-wing fit — 2026-08-25 (superseded immediately above)

- The successful but stringy right-wing fit print showed much more open rear-floor area outboard of the installed right-angle USB-C cable than needed. The user's green-marked photo directs the same amount of opening to the tablet side so the attached cable can still enter, seat, and turn behind the tablet.
- Kept the opening's proven **16 × 8 mm (Y × X)** envelope and moved it **4.0 mm inboard**. Relative to the fitted tablet's right edge at **X = 100.5 mm**, the opening now spans **X = 96.5–104.5 mm**: 4 mm inboard and 4 mm outboard. This restores the unused former **X = 104.5–108.5 mm** outboard half as rear floor and cuts the equal green-marked **X = 96.5–100.5 mm** tablet-side relief.
- This revision changes only the rear floor. The USB-C port center, **8.0 mm clear plug chamber above the floor**, recorded **6.50 mm plug projection**, 3.0 mm solid outer wall, continuous screen-facing cap, 16 mm opening width, tablet cavity allowances, cable clips, and downstream sleeve route are unchanged.
- CAD validation confirms the new inboard and outboard opening samples, restored outboard floor, retained 16 mm width, unchanged plug chamber volume at representative points, continuous outer closure, and watertight exports. The shift is not yet physically tested, and every earlier right-wing G-code is stale.

### Curved front opening after successful right-wing fit — 2026-08-25

- The corrected full-span right-wing print was **very stringy**, but the user reported very good clearance and fit: the tablet slides in very smoothly and seats snugly. This physically confirms the active **1.0 mm total X/Y and 0.8 mm Z allowance** for the right wing; preserve it.
- The same front-view test showed both rounded tablet corners visibly exposed beneath the square corners of the screen-facing lips. The approximately 7 mm tablet corner curve was already represented in the rear frame, but not in the front retaining opening.
- Added only a lip-plane corner treatment. The screen-facing opening is now **196.6 × 119.6 mm** with **5.3 mm** corners concentric to the nominal 7 mm tablet corners. It maintains the proven **1.7 mm nominal overlap** on the straight edges and continues that same overlap around all four curves, concealing the glass/body corners without narrowing the insertion cavity below the 2 mm front lip.
- The USB-C rear-channel dimensions and the existing outside-edge fillets/radii are unchanged in this revision; those remain separate requested changes. All prior right-wing G-code predates the new front-corner covers and is stale.

### Corrected right-wing slice with removable support strategy — 2026-08-25

- The user authorized printing the corrected full-span right wing and reported that the prior right-wing fit was slightly tight, possibly from difficult support removal.
- Prepared a fresh PLA slice from the current **111.33 × 139.00 × 14.20 mm** watertight right-wing STL, retaining rear-face-down orientation and the active full 139 mm USB-C closure.
- Changed only the support strategy for this retry: **snug, build-plate-only supports**, 55° threshold, 0.24 mm Z gap, 0.70 mm XY spacing, 3 interface layers, and a 5 mm brim. This avoids the prior grid supports' model-anchored scarring where possible while preserving overhang support.
- Validation passes the 10 mm³/s flow ceiling (6.3 mm³/s peak), bed footprint, PLA temperatures, and watertight-source checks. Estimated duration is 4 h 2 m with about 40.2 g PLA. The retained warnings are the known pre-macro bed-heat command and missing UI thumbnails.
- Printer status reported ready/idle and a fresh camera snapshot clearly showed the complete visible plate empty. The corrected job is ready to upload/start; physical fit remains pending.

This file is the durable record of confirmed dimensions, design choices, and later corrections. Update it whenever a decision is made or revised; do not rely only on conversation history.

## Persistent project rule

- Record every confirmed dimension and design decision in this repository as work progresses.
- Preserve superseded decisions as history, but clearly label them superseded and update the active design brief, parameters, generated metadata, and previews.
- Treat direct physical measurements and fit-test results as authoritative over web specifications or visual estimates.
- Keep `docs/current-design.md` and the root `AGENTS.md` synchronized with every active design change so new sessions load the correct model context immediately.

### Continuous V3 left outer wall — 2026-08-11

- The apparent top and bottom notches on the left wing were caused by the integral closure ending at the older 130 mm V2 Y span while the V3 receiver/shroud envelope had grown to 139 mm.
- Extended the left outer wall and its screen-facing cap to the full **139 mm V3 span**. The visible exterior is now continuous and rounded from top to bottom; the tablet-cavity corner openings remain internal/rear geometry for the measured tablet corner clearance.
- Kept the structural rail entry relief inside the rear/inner assembly path rather than exposing it on the finished exterior. Rebuilt the V3 exports, added edge-span validation, and regenerated the direct CadQuery previews.

### Updated right-wing fit print started — 2026-08-11

- The user authorized a quick fit print of the revised right wing after the continuous-left-wall change. The fresh source STL is the validated **111.33 × 139.00 × 14.20 mm** right wing; the old right-wing G-code was not reused.
- The PLA dimensional slice uses the existing rear-face-down orientation, 0.20 mm layers, three walls, 20% grid infill, 25 mm/s external perimeters, grid supports at a 55° threshold, **3 interface layers**, **0.20 mm Z gap**, 0.70 mm XY gap, and a 5 mm brim for the adhesion-prone filament.
- G-code validation passed with a 7.5 mm³/s peak flow against the 10.0 mm³/s ceiling, 48.8 g estimated filament, and an estimated 3 h 38 m 20 s. The only warnings are the known pre-macro bed-heat command and missing UI thumbnails.
- Printer status reported ready/idle, and a fresh 800 × 600 camera snapshot clearly showed the complete plate empty. The fit file was uploaded and accepted; the printer start endpoint returned `{"result":"ok"}`. Follow-up status showed `tablet_stand_v3_cradle_right_fit.gcode` printing at 0% with the bed heating to 60 °C.
- The job later completed; the user's photo confirms the same perimeter/USB-C corner features remained, so this print is treated as evidence that the 130 mm right closure was still present rather than as a successful test of the corrected full-span design.

### Right USB-C closure span correction — 2026-08-11

- The physical right-wing fit print showed that the earlier continuous-wall change had targeted only the left closure. The shared V2 USB-C end wall and cap were still 130 mm tall in Y while the active V3 perimeter is 139 mm, leaving the same top/bottom corner notches on the right wing.
- Added a V3-only continuous right outer closure that extends the USB-C end wall and screen-facing cap to the full **139 mm** span without changing the 16 × 8 mm rear cable opening or the tablet-side plug pocket. Added validator samples at both outer corners; the next right-wing slice must use this corrected geometry.

### Rounded front frame and preserved stand alignment key — 2026-08-10

- The supplied tablet mesh has an approximately 7 mm plan corner curve. The active V3 front-frame opening now uses a 7.0 mm inner corner radius, and the outer frame uses a 17.0 mm radius (inner radius plus the 10 mm frame width) so the rounded wall remains structurally uniform.
- Exposed rail/wall corners remain within the 3 mm wall limit at 1.45 mm, while lip plan corners are 1.05 mm; longitudinal edge fillets are 0.70 mm on rails/walls and 0.60 mm on lips. The integral left closure keeps its 1.70 mm plan corner and 0.85 mm edge fillet.
- V3 did not lose the stand-alignment feature: it still exports one 35 × 15 × 1.8 mm cross-key for the rear-bracket-to-sleeve joint. The old cradle-to-bracket key was intentionally removed because the bracket bonds only to the fixed right wing; the removable left wing remains adhesive-free.
- Rebuilt V2/V3 exports, passed both validators, and regenerated the direct CadQuery multi-view preview. The previously printed right-wing G-code predates this finish revision and is stale; it must not be reused for the revised geometry.

### Continuous smooth front perimeter — 2026-08-11

- The user requested a stronger Apple-like silhouette: the active outer frame radius is now 28.0 mm while the tablet-matching inner radius remains 7.0 mm.
- Added continuous top and bottom edge rails to absorb/shroud the outer tongue/receiver joiners. The structural joiners remain on the rear side of the perimeter, while the screen-facing view reads as a straight, uninterrupted edge with no center bumps.
- This changes the left production wing envelope to 125.00 × 139.00 × 14.20 mm; the right remains 111.33 × 139.00 × 14.20 mm. Both still fit the 220 mm bed and preserve the tablet cavity, USB-C opening, button channel, tongue clearances, and one bracket-to-sleeve alignment key.
- Rebuilt and validated the V3 exports and regenerated the direct CadQuery preview. All previous production G-code remains stale until a fresh support/adhesion-reviewed slice is made for this geometry.

### Right-wing production print started — 2026-08-10

- The user explicitly authorized printing the right-hand cradle wing and confirmed the bed was clear. The watertight `tablet_stand_v3_cradle_right.stl` was inspected at 111.33 × 139.00 × 14.20 mm and fits the confirmed Ender-3 Pro bed.
- Fresh PLA G-code used the functional profile (0.20 mm layers, five walls, 40% grid infill, 215/210 °C nozzle, 60 °C bed), plus snug supports at a 45° threshold and a 5 mm brim because the part inspection flagged 6% overhang area and prior PLA prints had adhesion defects.
- Independent G-code validation passed the 10 mm³/s flow ceiling (7.5 mm³/s peak), bed footprint, PLA temperatures, and estimated 3 h 30 m 51 s / ~51 g usage. It reported only the known heat-order and missing-thumbnail warnings.
- A fresh 800 × 600 printer camera snapshot showed the complete visible build plate clear; the machine reported ready. Moonraker accepted the uploaded file and `/printer/print/start` returned `{"result":"ok"}`. Follow-up status showed `tablet_stand_v3_cradle_right.gcode` printing at 0% with the bed heating to 60 °C. The left wing and remaining parts are not authorized by this action.

### Right-wing print support-removal feedback — 2026-08-10

- The right-wing job completed successfully. The user reported that the support material was difficult to distinguish from the model and nearly impossible to remove with this PLA.
- The G-code contains roughly 4,000 support moves, concentrated under the USB-C/receiver bridge regions and small edge overhangs, plus a 5 mm brim. For subsequent parts, review a more removable support strategy (build-plate-only where possible, larger Z/XY separation, and fewer interface layers) before authorizing another production print.

## Confirmed dimensions

| Item | Confirmed value | Source/status |
|---|---:|---|
| Tablet envelope | 200 x 123 x 8.4 mm | Supplied `tinker.obj` bounding box |
| Existing tube OD | 32.0 mm | User measurement |
| Printed sleeve ID | 32.2 mm | User fit-tested; tight working fit |
| Sleeve body length | 50 mm | Version 1 design value; physical tube availability still to confirm |
| Clear tube engagement | 51 mm | Version 1 design value with 3 mm solid seating cap |
| Sleeve seating cap | 3.0 mm | Version 1 deterministic insertion stop |
| Sleeve wall | 4.0 mm | Version 1 design value |
| Tablet fit allowance | 1.0 mm total X/Y; 0.8 mm Z | Version 1; test coupon required |
| Screen tilt | 10 degrees back from vertical / 80 degrees above horizontal | Corrected user decision; kiosk-like |
| Long-edge relationship | Top is higher and farther from user; bottom is lower and nearer | Confirmed user decision |
| USB-C location | Center of right short edge in landscape | User measurement |
| Plug projection | 0.256 in / 6.50 mm | User measurement |
| Flat cable thickness | 0.6 mm | User measurement |
| Flat cable length | About 2 in / 50.8 mm before braided transition | User measurement |
| Right-angle pigtail reach | 51.4 mm marked length | User photo; precise endpoints still to confirm |
| Downstream connector body | 9.6 mm marked dimension | User photo; axis/meaning still to confirm |
| Round braided cable diameter | 3.45 mm | User measurement; cable after the pictured adapter |
| Available screw hardware | M3 | User has it, but the active stop is explicitly screw-free |
| Power/volume group span | 20–60 mm from landscape top-left | User measurement |
| Power/volume button section | 2 mm wide across tablet thickness, centered; 1 mm edge protrusion | User measurement |

## Active design decisions

- Landscape tablet orientation.
- Simple, sleek, skeletal support rather than a bulky closed enclosure.
- Tablet slides in from the left through narrow long-edge rails.
- V3 uses a fully enclosed removable left cradle wing instead of a separate cap. Three integral tongues slide +X into closed-back right-wing receivers; one tapered printed cross-wedge locks the lower joint and remains removable for tablet service.
- The right edge has a continuous full-depth screen-facing cap backed by internal stops and a solid outer USB-C wall. No tablet-edge or recessed plug-pocket segment is exposed from the front; the low-profile right-angle adapter still turns immediately behind the tablet instead of sending the cable straight out through the right wall.
- The 51.4 mm pigtail and downstream connection remain largely hidden across the open back. The confirmed 3.45 mm braided section snaps into two open rear clips and a rear-facing external sleeve channel, then exits downward near the tube.
- Between the nearer rear clip and sleeve channel, the cable stays in open space: it drops outside the right gusset, passes behind the sleeve, and enters through the channel's rear snap opening. Previewed cable geometry must never cross a holder solid.
- The sleeve channel uses 4.15 mm internal clearance, a 2.8 mm snap opening, and a shallow 1.2 mm embed. It leaves at least 2.8 mm of sleeve wall and does not cut into the tested 32.2 mm tube bore.
- Exposed perimeter, rail, lip, and stop edges use larger plan radii plus 0.65/0.45 mm longitudinal edge fillets so the print feels softer without becoming bulky.
- The holder installs by sliding a closed 32.2 mm ID sleeve down over the accessible top of the vertical tube.
- With the tablet nearly vertical, the sleeve is centered left-to-right and offset 24 mm behind the screen plane.
- The sleeve/collet bottom is level with the installed holder's lower long edge at Z = -64.53 mm. This lowers the complete rear assembly by 14.53 mm without changing sleeve fit or engagement.
- V3 divides the cradle into two rear-face-down wings joined without glue by three integral tongues and one removable lower cross-wedge. The same 4 × 4 mm locking channel can accept an M3 bolt after the actual head/nut/length dimensions are confirmed.
- The rear bracket bonds only to the fixed right cradle wing so the left wing remains removable. The bracket-to-sleeve bond retains one loose-fit 35 × 15 × 1.8 mm printed alignment key; no adhesive belongs on the removable center joint.
- The bracket carries the two open braided-cable clips so the cradle keeps a completely flat rear print datum.
- Routine previews use direct in-memory CadQuery tessellation with a depth-buffered renderer. The headless fallback uses VTK; Blender is reserved for optional polished presentation renders.

## Revision history

### V3 tongue/receiver and corrected wedge coupon pass — 2026-08-10

- The user reported major bed-adhesion failure, lifted/stringing extrusion, and poor layer quality in the combined PLA coupon. Even with those defects, the production tongue and receiver pieces fit together. This physically passes their insertion-clearance gate; retain 0.50 mm total root and 1.10 mm total lead clearance.
- The corrected wedge/pin was physically tested after the first floating-body layout failed. It retained and released successfully, so the removable-joint mechanical gate is passed; do not change the confirmed tongue/receiver clearances.
- The original combined support-free coupon G-code remains stale. Fresh full-part slices must account for this user's poor PLA adhesion/stringing and show support/first-layer review before either full wing is started.

### Combined three-piece V3 lock coupon print started — 2026-08-09

- The user explicitly authorized printing all three coupon pieces. Added a reproducible 77.91 × 33.12 × 9.00 mm combined CadQuery plate containing the unchanged production tongue crop, receiver crop, and wedge.
- PrusaSlicer retained the modeled rear-face-down orientation and generated zero support extrusion. The job uses PLA, 0.16 mm layers, three walls, 20% grid infill, a 5 mm brim, 205/200 °C nozzle, 60 °C bed, and 1.0 mm direct-drive retraction at 40 mm/s.
- Independent G-code validation reports a 100 × 46 × 9 mm brim-inclusive footprint, 31m 11s estimated time, about 3.1 g, and 6.2 mm³/s peak flow against the 10 mm³/s machine ceiling. The retained pre-macro heat-order and missing-thumbnail warnings do not affect model motion.
- The printer reported ready and cool after its prior job. A fresh 800 × 600 camera snapshot clearly showed the complete visible plate empty. `tablet_stand_v3_lock_coupon_all3_pla.gcode` was uploaded and the print start was accepted; physical fit and retention results are pending.

### Removable tongue-and-wedge center joint supersedes V3 glue seam — 2026-08-09

- The user rejected permanent cradle glue and selected a screw-free removable middle joint, with existing M3 hardware available only if necessary.
- Replaced the stepped glue seam and three loose adhesive splice keys with a straight center split and three integral +X tongues. The upper/lower tongues are 6 mm tall bed-supported blocks in reinforced receivers; the center tongue stays within the 3 mm rear plate. All receivers have open entrances and closed seating backs.
- Each tongue inserts 18 mm. The close seated/root fit has 0.50 mm total clearance and the tapered lead has 1.10 mm total clearance, derived from the physically successful V2 PLA plug result but enlarged substantially for strength.
- Added one removable lower cross-wedge, tapering from 3.70 to 3.30 mm with a 7 mm pull head. It passes along +Y through an aligned 4 × 4 mm channel in the lower tongue and receiver. The channel's 4 mm ceiling is within the confirmed support-free PLA bridge rule.
- The same channel clears an M3 shaft for a bolt/washer/nut fallback. Do not finalize metal hardware pockets until the user's exact M3 head style, length, washer, and nut dimensions are measured.
- The left wing is now 125.00 × 135.50 × 14.20 mm and the right wing 111.33 × 139.00 × 14.20 mm; both are single watertight solids and remain comfortably inside the 220 mm bed.
- Validation confirms zero intersection at seven left-wing insertion positions, no seated wing overlap, a collision-free wedge insertion path, retained button/USB-C geometry, a continuous integral left wall, and watertight production/coupon exports.
- The rear bracket bonds only to the fixed right wing and merely contacts the removable left wing. The bracket-to-sleeve bond keeps one printed alignment key. This makes the tablet serviceable without disturbing the tube mount.
- Exported exact lower-joint left, right, and wedge coupons. A physical coupon test is required before slicing either full cradle wing; do not infer final wedge retention from CAD alone.
- Added a combined `lock_coupon_all3` print-plate export containing one unchanged copy of each coupon component. The three islands have more than 10 mm edge clearance so a 5 mm brim does not join them; this is the authorized single-job layout for the physical test.

### V3 splits the near-bed-width cradle into two printable wings — 2026-08-09 (adhesive joint superseded later the same day)

- The user requested another modeling approach after the full V2 cradle measured 215 mm wide on the 220 mm Ender-3 Pro bed, then authorized a V3 concept for visual review.
- The first V3 render incorrectly retained the separate V2 end cap even though the two-piece cradle itself provides the tablet-loading split. The user rejected that redundancy. V3 now has one continuous rounded left wall integrated into the left wing, and no separate end cap, tapered plug, socket, receiver bulge, screw, or nub.
- V3 assembly now seats the tablet in the USB-C/right wing first, brings the enclosed left wing onto the long edges, and joins the two wings at the center seam. Adhesive assembly captures the tablet, so serviceability must be explicitly accepted before bonding.
- Split the exact tested cradle geometry along a 0.35 mm-clearance stepped planar seam. The seam runs at X = −8 mm near both long rails and X = +8 mm through the center, creating a 16 mm dogleg at Y = ±35 mm without an undercut, trapped support, or tall print orientation.
- The corrected fully enclosed left wing validates at 114.83 × 130.00 × 14.20 mm and the right wing at 119.33 × 130.00 × 14.20 mm. Both are single watertight solids, print rear-face-down, and leave generous margin on the confirmed 220 × 220 mm bed.
- Added three identical 44 × 6 × 1.6 mm loose splice keys in 46 × 7.2 × 1.9 mm rear recesses. One bridges each long rail and one bridges the center spine; all sit 0.20 mm below the rear face. The existing 74 × 36 mm rear bracket also spans and bonds across the center seam.
- Preserve the tested tablet allowance, concealed button groove, open USB-C cable rectangle, tube sleeve, cable route, and exposed fillets. The successful twin tapered coupon remains historical V2 fit evidence but that joint is intentionally absent from corrected V3. V3 is rendered and validated but not yet sliced or approved for printing.
- Keep V2 only as the exact geometry basis during this comparison. If the V3 visual review passes, promote V3 and archive the V2-only workflow rather than maintaining two production versions.

### Twin tapered plug/socket coupon passes — 2026-08-09 (V2 evidence; superseded in V3)

- The user physically tested the tightened rev3 plug against the already-printed enlarged socket and reported that the fit was great. This passes the twin-plug mechanical fit gate for the active screw-free left cap.
- Keep the 0.45 mm total root and 0.85 mm total tip clearances. No further fit-coupon geometry change is needed before production slicing.
- The later V3 split-cradle decision removes the separate cap, plugs, and sockets entirely. Keep this result only as V2 process/fit history; do not reuse any pre-V3 full-part G-code.

### Slightly tighten the successful enlarged socket fit — 2026-08-05

- The enlarged socket and thicker plug fit reliably in the user's PLA, but the user reported slight looseness. Retain the printed socket and tighten only the plug so no second socket print is needed.
- Increase the plug from 2.40 × 3.20 mm at the root / 2.00 × 2.80 mm at the tip to 2.55 × 3.35 mm / 2.15 × 2.95 mm. This targets 0.45 mm total root clearance and 0.85 mm total tip clearance while remaining materially larger than the broken first plug.
- Prepare and validate a plug-only coupon. The revised G-code validates at about 6 min 0 s, 0.3 g, 5.7 mm³/s peak flow, and no support or bed-clearance errors apart from the profile's generic heat-order and thumbnail warnings. Do not print the full cap until this intermediate fit is confirmed.

### Loosen and strengthen twin-plug fit after PLA coupon failure — 2026-08-05

- The user physically tested the first socket/plug pair. It was too tight to seat reliably in the actual PLA, and the small tapered plug broke during fitting. This physical result supersedes the prior 0.25 mm total root-clearance target.
- Enlarged the socket from 2.40 × 3.20 mm to 3.00 × 3.80 mm and enlarged the plug from 2.15 × 2.95 mm at its root / 1.80 × 2.60 mm at its tip to 2.40 × 3.20 mm / 2.00 × 2.80 mm. The new total root clearance is 0.60 mm, with 1.00 mm total tip clearance.
- Increased receiver reinforcement to 5.8 mm across Y and 6.8 mm across Z while preserving at least 1.3 mm of surrounding material. The cradle envelope becomes 215 × 135.6 × 14.8 mm and remains within the confirmed 220 × 220 mm bed.
- Regenerate and physically test the replacement socket and plug coupon before slicing or printing the full cradle/cap. Do not reuse the previous coupon pieces as final fit references.

### Twin tapered rail plugs replace the failed dovetail — 2026-08-04

- The supported dovetail coupon physically failed its serviceability goal: support could not be removed reliably from the narrow captured groove. The user selected twin tapered plugs as the replacement screw-free joint.
- Added one horizontal plug and socket at each long-edge rail. Each 12 mm plug tapers from 2.15 × 2.95 mm at its root to 1.80 × 2.60 mm at its tip; each socket is 2.40 × 3.20 mm with 0.25 mm total root and 0.60 mm total tip clearance.
- Both plug and socket use a house-shaped cross-section. Vertical walls and a two-face 45-degree roof eliminate unsupported flat fit surfaces, while 45-degree underside ramps blend the reinforced socket bodies into the cradle.
- Preserved the concealed 2 mm-high × 1.2 mm-deep top button groove, solid 1.8 mm outer rail wall, rounded cap, and absence of screws, hooks, detents, or a lower nub.
- Validation confirms both seating ends, minimum 1.2/1.3 mm receiver walls, zero intersection at six horizontal insertion positions, watertight production/coupon STLs, and a 215 × 133.6 × 14.2 mm cradle envelope. The multiview and exact coupon preview were regenerated and inspected.
- Prepared the exact socket and plug coupons as separate support-free jobs for the user's string-prone PLA: 0.16 mm layers, three walls, 20% grid, 5 mm brim, 205/200 °C, and 1.0 mm retraction at 40 mm/s. They validate at about 19 min 23 s / 1.0 g and 5 min 44 s / 0.3 g without model-stability warnings.
- All previous full-cradle, supported-cradle, combined-coupon, and end-stop G-code is stale. A physical twin-plug fit test is required before regenerating the complete cradle and cap slices.

### Sleek dovetail stop and clean lower-left corner — 2026-08-03 (superseded 2026-08-04)

- The user rejected the first screw-free implementation's visible landing nub, small rear hooks, and detent bumps in favor of a sleek tongue-and-groove joint like the supplied reference image.
- Replaced the separate hooks and detents with one continuous top-entry dovetail. Its cradle groove has a 1.30 mm mouth and 2.30 mm internal head; its stop tongue has a 1.80 mm head, producing 0.25 mm mechanical capture per side and 0.50 mm total sliding clearance at the head.
- Closed the groove internally at Y = −54.5 mm to establish the seated position without an external ledge. Removed the entire lower landing/nub and restored the cradle envelope to 215 × 130 × 14.2 mm.
- Rounded the stop's outside plan corner to 1.70 mm and its exposed edges to 0.70 mm, preserving the clean continuous lower-left outline.
- Sampled the complete top-down insertion path at thirteen offsets from 130 mm to fully seated; every position has zero solid intersection. The cradle, stop, and exact two-piece coupon remain watertight.
- Updated ADR-0002 as an implementation refinement: the accepted screw-free guided-slide decision remains, while its former landing/hook/detent implementation is superseded.
- Regenerated the two-piece left-slide PLA coupon with a 5 mm removable brim and no supports; validation reports 33 min 13 s, about 5.8 g, and 7.6 mm³/s peak flow. It was not uploaded or started.
- Regenerated the full-cradle support review. The recommended support-free job validates at 4 h 8 min, 60.7 g, and X = 3–217 mm; the snug-support comparison validates at 4 h 28 min, 67.4 g, and places support on the long lips and end features. Neither was uploaded or started.
- Prepared the separate end stop bridge-face down with a 5 mm brim and no supports; validation reports 49 min 22 s and 9.2 g. It was not uploaded or started.

### Supported left-slide coupon retry for string-prone PLA — 2026-08-03 (superseded 2026-08-04)

- The first physical two-piece left-slide coupon failed as a print: the stop crop developed loose/collapsed extrusion beneath its ledge and the shared job showed severe travel stringing. This result does not establish dovetail fit and overrides the earlier support-free slice recommendation.
- Kept the exact production tongue, groove, closed bottom, and fit clearance unchanged. Rotated the stop onto its broad outside wall face so its dovetail builds vertically; this changes only manufacturing orientation, lowers the full stop from 14.2 mm to about 6.8 mm, and increases its estimated bed contact from 803 mm² to 1,778 mm². Increased the combined plate's inter-part spacing from 10 mm to 28 mm, leaving an 18 mm clear gap between separate 5 mm brims.
- The retry uses 45-degree grid supports, a cooler 200 °C nozzle after a 205 °C first layer, and slower external/perimeter motion for the user's confirmed dry but string-prone PLA. The full cradle and end-stop G-code remain unapproved pending a successful physical coupon.
- The validated retry uses 0.16 mm layers, three walls, 20% grid infill, 45-degree grid supports with 0.2 mm Z / 0.4 mm XY gaps, a 5 mm brim, 1.0 mm retraction at 40 mm/s, 25 mm/s external perimeters, and 30 mm/s perimeters. It estimates 40 min 49 s and 5.0 g with 7.5 mm³/s peak flow; actual support paths were rendered and visually inspected before upload.
- Started the corrected coupon after printer status reported ready/complete and a fresh camera image clearly showed the visible build plate empty. Moonraker confirmed the uploaded file's 0.16 mm layers, 205/200 °C temperatures, 14.2 mm height, and 2,449 s estimate before the job entered `printing` and began heating the bed to 60 °C.

### Screw-free slide stop and softened outside edges — 2026-08-02 (joint geometry superseded 2026-08-03)

- The user rejected the M3 hole and requested a left edge that simply slides downward, seats on a projecting lower-left cradle edge, stays through friction, and can optionally receive a drop of glue.
- Removed the complete M3 boss, pilot, stop tab, and clearance hole. Added a 7 × 5.5 × 3 mm lower landing, a 4 mm rail-free insertion lead, two 6 mm friction ribs with 0.05 mm nominal insertion interference, matching 6.4 mm detent grooves, and two rear hooks with 0.20 mm clearance below the cradle datum.
- Sampled the stop throughout its local −Y insertion path. Hard geometry remains collision-free; only the intended friction ribs overlap the base edge during travel, at no more than 0.60 mm³ combined, and the fully seated stop has zero overlap.
- Increased exposed plan-corner radii from 1.2 to 1.45 mm on rails/walls and from 0.8 to 0.95 mm on lips. Added 0.65 mm perimeter/rail edge fillets and 0.45 mm lip edge fillets to remove the sharp longitudinal edges reported on the physical print.
- Added two exact production-crop STLs for testing the landing, hook clearance, downward travel, and friction detents before printing the revised 217 × 135 mm cradle.
- ADR-0002 supersedes the M3 clause in ADR-0001 while retaining the four-module support-minimized architecture. The previous full-cradle G-code predates this geometry and is invalid for production.
- Prepared both coupon pieces on one 33.75 × 50 mm plate with a removable 5 mm brim, three walls, 20% grid infill, and no supports. The validated PLA job estimates 38 min 41 s and 6.1 g; it was not uploaded or started.
- Replaced the stale cradle G-code with revised slices. The recommended support-free job validates at 4 h 34 min, 61.1 g, and X = 2–218 mm extrusion; the snug-support comparison validates at 4 h 52 min and 66.8 g but contacts the long rail lips and right-end features. Neither was uploaded or started.

### Archive superseded V1 from the active tree — 2026-08-02

- The user confirmed that V1 is superseded and should no longer consume maintenance or review effort.
- Removed the generated `build/v1/` artifacts, V1 validator, V1 preview entrypoint, and legacy Blender renderer from the active working tree. The complete prior state remains recoverable at Git commit `560c6e8`.
- Renamed and trimmed the former shared source into `cad/tablet_stand_core.py`, which now contains only active measured parameters plus the cradle and sleeve geometry required by V2. V2 no longer imports a module named for V1.
- Reduced the mandatory model workflow to the three active V2 build, validation, and direct-preview commands.

### Full cradle PLA slice and support review — 2026-08-02

- The user authorized preparation of the full tablet-holder print but required visual review of the slice and supports before any printer upload.
- Kept the cradle on its production rear-face datum. Standing it vertically would fit the conservative 210 mm safe envelope but create extensive support, a 216 mm-tall weak print, and poorer rail dimensional fidelity.
- The 216 mm cradle fits the configured 220 mm bed at X = 2–218 mm only after disabling the profile's optional 6 mm skirt. The no-support candidate validates at 4 h 39 min, about 61.8 g, and 7.5 mm³/s peak flow.
- Generated a snug 45-degree support comparison. It adds about 29 minutes and 9.4 g, reaches the complete X = 0–220 mm span, and places support along the long retaining rails and right-end features.
- Selected the support-free slice as the recommended candidate because production-orientation coupons already validated the short unsupported rail geometry, while supports consume all bed margin and contact fit-critical surfaces. Neither slice was uploaded or started.
- Added `scripts/render_gcode_support_preview.py` and `tablet_stand_v2_cradle_support_review.png` to visualize actual PrusaSlicer model paths in blue and support paths in orange.

### Concealed 2 mm internal button groove — 2026-08-02

- The user rejected the exposed through-slot: the power/volume relief must be a small internal channel rather than an opening through the top rail's outer face.
- Replaced the prior 3 mm through-slot with a 2 mm-high × 1.2 mm-deep groove in the rail's inner face, centered on the measured buttons. The groove clears their 1 mm projection with 0.2 mm depth allowance.
- Preserved a continuous 1.8 mm exterior wall, above the 1.26 mm recommended PLA wall for the confirmed 0.4 mm-nozzle process, plus the complete screen-facing retaining lip.
- Kept the groove open only at the left slide-in entrance and continued it 5 mm beyond the measured seated button group so the insertion path remains unobstructed without exposing the channel on the outside of the holder.
- Regenerated the production-orientation PLA coupon G-code at 0.20 mm layers, three walls, 20% grid infill, and no supports. Validation found 7.5 mm³/s peak flow, a 23 min 20 s estimate, and about 5.3 g of filament; it was not uploaded or started.

### Power/volume slide-through channel — 2026-08-02 (superseded)

- The user measured the complete landscape-top power/volume group from 20 to 60 mm rightward from the tablet's top-left corner. The buttons are 2 mm wide across the 8.4 mm tablet thickness, centered on that thickness, and protrude 1 mm from the tablet edge.
- Added a 3 mm-high opening centered on the buttons, giving 0.5 mm PLA process clearance above and below. This exposed through-slot was rejected and replaced by the concealed 2 mm internal groove above.
- Preserved the continuous screen-facing retaining lip and the lower rail wall outside the button-height band. The channel ends in intact top-rail wall after its 5 mm overrun.
- Added `tablet_stand_v2_button_fit_coupon.stl`, an exact 73.5 × 11 × 14.2 mm crop of the production top-left rail, for physical insertion and seated-clearance testing before a full cradle print.
- Prepared its production-orientation PLA G-code at 0.20 mm layers, three walls, 20% grid infill, and no supports. Validation found 7.5 mm³/s peak flow, a 21 min 51 s estimate, and about 4.8 g of filament; it was not uploaded or started.

### Restore rail allowances and simplify cable opening — 2026-08-02

- The second physical fit test showed that removing the Y/Z allowances was the wrong direction. Restored the original 1.0 mm total X/Y and 0.8 mm Z tablet allowances.
- The cable still could not pass through the T-shaped combination of a 3 × 16 mm slot and 6 × 8.5 mm notch because the original narrow section would not accept the cable's thick portion.
- Replaced the complete T-shaped opening with one rectangular opening that retains the original 16 mm width and spans the full 8 mm pocket depth from the tablet cavity to the outer wall.
- **Superseded by the 2026-08-02 power/volume channel revision:** at this point the top long-edge rail was still continuous and button measurements had not yet been supplied.
- Regenerated and validated the PLA right-side fit-test G-code at 0.20 mm layers, three walls, 20% infill, and no supports. It estimates 1 h 25 min and 18.6 g and was not started.

### Tightened tablet rail fit on both tested axes — 2026-08-02

- The user confirmed that the first PLA right-side coupon was loose both between the two long-edge rails and front-to-back under the retaining lips.
- Reduced total Y allowance from 1.0 mm to 0.0 mm and Z allowance from 0.8 mm to 0.0 mm, using the measured 123 × 8.4 mm tablet envelope directly on both tested rail axes. Preserved the 1.0 mm total X allowance for slide-in length and end-stop tolerance.
- Kept the holder's 130 mm outer Y span fixed. Each long-edge wall grows inward by 0.5 mm, avoiding any change to the outside frame, Z = -64.53 mm lower-edge/sleeve alignment, or already-printed rear bracket and sleeve.
- Started the second PLA right-side test piece after a fresh camera check showed the complete build plate clearly empty. It uses the established 0.20 mm, three-wall, 20% grid, support-free process and is estimated at 1 h 23 min and 18.0 g.
- This is intentionally a physical-test-driven nominal fit; verify that the second PLA coupon slides without force before committing to the full cradle.

### Open cable-body notch from physical coupon test — 2026-08-02 (superseded)

- The user reported that the first PLA right-side coupon fit the tablet reasonably well but the attached right-angle USB-C cable body could not enter the closed rear-turn slot.
- The user's physical test and photo establish an 8.5 × 6 mm required notch. The active design now opens that measured Y × X notch from the tablet cavity into the existing 3 × 16 mm rear pigtail slot.
- Preserved the continuous screen-facing cap, solid outer USB-C wall, 8.0 mm-clear plug pocket, and existing broad flat-pigtail slot. The new notch is confined to the rear pocket floor and provides a lateral installation path for the attached cable.
- Regenerated the PLA coupon G-code with the established 0.20 mm, three-wall, 20% infill, support-free process. The revised validated job estimates 1 h 25 min and 18.7 g; it was prepared but not started.
- The user also reported that tablet retention was slightly loose by about 1 mm on both rail axes; the subsequent fit revision supersedes the original Y/Z allowances.

### Right-side tablet and USB-C fit coupon — 2026-08-02

- Selected a right-end coupon instead of a left/end-stop coupon so one small print tests the uncertain production rail fit and the actual USB-C adapter route together.
- The coupon is an exact X = 78.0–111.5 mm crop of the active V2 cradle, retaining 33.5 mm of both long-edge rails, the full right-side cap and internal stops, the 8.0 mm-clear plug pocket, solid outer wall, and 3 × 16 mm rear-turn slot.
- The coupon preserves the production cradle's rear-face-down print orientation and its 1.0 mm total X/Y and 0.8 mm Z tablet allowances. PLA is the user-selected test material.
- Started the physical coupon on the confirmed Ender-3 Pro profile at 0.20 mm layers, three walls, 20% grid infill, 210 °C PLA / 60 °C bed, and no supports. The unsupported short rails and right-side bridges intentionally reproduce the production cradle's print conditions; the validated G-code estimates 1 h 25 min and 18.8 g.
- A successful physical test requires the tablet to slide without force, seat at the right stop without rocking, accept the USB-C adapter, and let the flat pigtail turn behind the tablet without pinching.

### Loose-fit glue alignment keys — 2026-08-01

- A user PLA+ print test found the original cross keys would not enter their grooves; the prior 0.25 mm total planar allowance was inadequate in the actual process.
- Retained the existing 36.25 × 16.25 × 4.25 mm groove profiles so replacement keys remain compatible with modules that may already be printed.
- Reduced each key to 35 × 15 × 1.8 mm, yielding at least 1.25 mm total in-plane clearance and 0.50 mm total thickness clearance, and added 0.4 mm top/bottom edge relief against first-layer flare.
- Kept two separate keys: one aligns the cradle-to-bracket joint and the other aligns the bracket-to-sleeve joint. The keys locate parts during cure; adhesive carries the finished joints.

### Support-minimized keyed-glue V2 — 2026-07-28

- Evaluated the monolithic V1 main STL in its viable sleeve-vertical orientation. Approximate triangle analysis flagged about 7,700 mm² of downward-facing surface beyond a 45-degree support rule, including the full-width upper rail and the 32.2 mm sleeve-cap ceiling.
- Split the active V2 main structure into a cradle, rear tilt bracket, and sleeve while preserving the 200 × 123 × 8.4 mm tablet envelope, 80-degree screen angle, 32.2 mm tested bore, 51 mm engagement, 3 mm seating cap, 24 mm rear offset, and Z = -64.53 mm sleeve-bottom alignment.
- The cradle prints on a 216 × 137.5 mm rear datum; the bracket prints on a 60 × 28 mm foot; and the sleeve prints upside down on a 60 × 46 mm flange with its tube-entry bore open upward.
- The user confirmed that the main structural parts may be glued. Removed the provisional eight-screw structural scheme and retained only the removable end stop's single M3 screw.
- **Superseded by the 2026-08-01 fit-test correction:** added matching half-depth cross grooves to both glue joints and one 36 × 16 × 2 mm alignment-key STL to print twice. Each groove is 1.15 mm deep with 0.25 mm planar clearance.
- Relocated the two open cable clips to the rear bracket and moved the end-stop screw to a front-accessible local-Z boss outside the tablet cavity.
- All five V2 STL files validate as watertight single components. Approximate flagged overhang area is about 2,870 mm² across all parts, primarily short rail lips, shallow groove roofs, and small clip details rather than tall support towers.

### Fully enclosed right-side face — 2026-07-21

- Replaced the two separated screen-facing right retaining pads and narrow central pocket ceiling with one continuous full-depth cap spanning the entire tablet short edge and plug-pocket depth.
- Preserved the two internal locating walls, solid outer USB-C end wall, 8.0 mm clear plug pocket, and 3 × 16 mm rear pigtail turn slot.
- Neither the tablet's right edge nor the recessed pocket is partially exposed in the front view; cable installation and the left-to-right slide-in path remain unchanged.

### Preserve clips; route between solids — 2026-07-21

- Restored the two open rear C-clips and the external sleeve snap channel after rejecting connector-pass eyelets.
- Corrected only the free cable span: it now drops outside the right gusset, sweeps behind the sleeve with cable-radius clearance, and enters the channel through its rear opening.
- The cable does not pass through the backplate, gussets, sleeve wall, or tube bore.

### Rear sleeve lowered to holder bottom — 2026-07-20

- Lowered the complete sleeve/collet and its external cable channel by 14.53 mm so the sleeve bottom and holder's lower long edge share Z = -64.53 mm in the installed orientation.
- Preserved the 32.2 mm tested bore, 40.2 mm OD, 51 mm clear engagement, 3 mm seating cap, and 24 mm rear offset.
- Extended the two gussets down to the new sleeve position while retaining their original holder-side anchors.
- The open cable span now runs visibly downward and backward from the center rear clips into the lowered sleeve channel; no larger connector is made captive.

### Braided cable channel implemented — 2026-07-20

- Confirmed the cable after the pictured right-angle adapter is 3.45 mm diameter round braided wire.
- Replaced the generated straight-out right-wall groove with a solid outer wall and a 3 × 16 mm rear turn slot for the flat pigtail.
- Added two open rear C-clips and a downward, rear-facing sleeve channel sized to 4.15 mm ID with a 2.8 mm snap opening.
- The sleeve channel embeds only 1.2 mm into the 4 mm sleeve wall, leaving 2.8 mm minimum material over the unchanged 32.2 mm tube bore.
- The larger 9.6 mm-marked connector stays outside every captive feature for installation and service.

### Rear-hidden right-angle cable route — 2026-07-20

- **Superseded:** the V1 straight-out flat-cable groove through the outer right wall.
- **Active intent:** the right-angle adapter wraps immediately behind the tablet; its photo-marked 51.4 mm pigtail and downstream connection stay behind the open back, and the cable then routes to a groove/clip on the sleeve or collet before exiting near the tube.
- The user photo marks 9.6 mm at the downstream connector body, but the measurement axis was not yet confirmed. At this stage the downstream cable diameter and final sleeve exit direction were also still required before changing fit-critical sleeve geometry.
- Prefer open, serviceable rear clips/channel features that do not require feeding the larger connector through a closed tunnel and do not reduce the proven 32.2 mm sleeve bore.

### Closed USB-C end and softened corners — 2026-07-20

- **Superseded:** separated right corner stops with an entirely open center and exposed cable saddle.
- **Active:** the corner stops still locate the tablet, but a closed outer right end encloses the measured 6.50 mm plug projection. Its chamber is open toward the tablet so the cable can be positioned first and the tablet slid onto the connector from the left.
- Version 1 uses 1.50 mm extra plug-depth clearance, giving an 8.0 mm clear pocket, and a provisional 24 mm wide × 1.8 mm high exit groove around the 0.6 mm flat cable. Width remains a required measurement before printing.
- Version 1 rounds exposed wall/rail corners by 1.2 mm and lip corners by 0.8 mm.

### Kiosk-angle correction

- **Superseded:** 10 degrees above horizontal, nearly flat.
- **Active:** 10 degrees back from vertical, equivalently 80 degrees above horizontal, nearly upright like a kiosk.
- The top remains higher and farther from the user than the bottom.
- This correction changes the mount from an underside pedestal junction to a rear-offset sleeve-and-gusset junction.

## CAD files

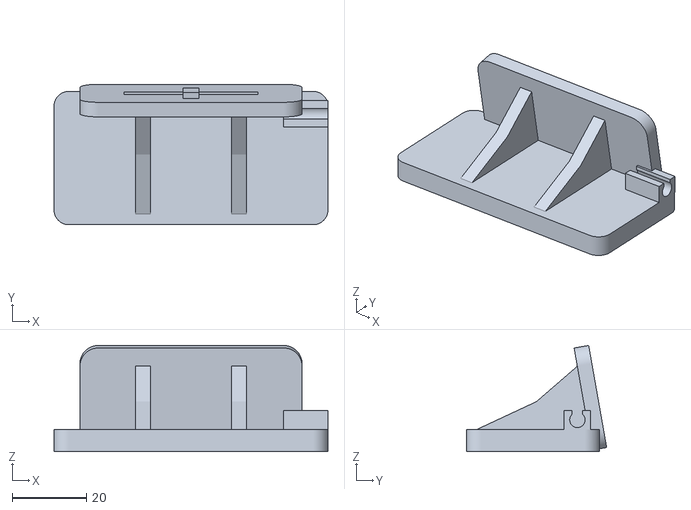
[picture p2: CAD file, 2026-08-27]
build/v3/tablet_stand_v3_rear_bracket.stl
74.0 x 37.9 x 28.7

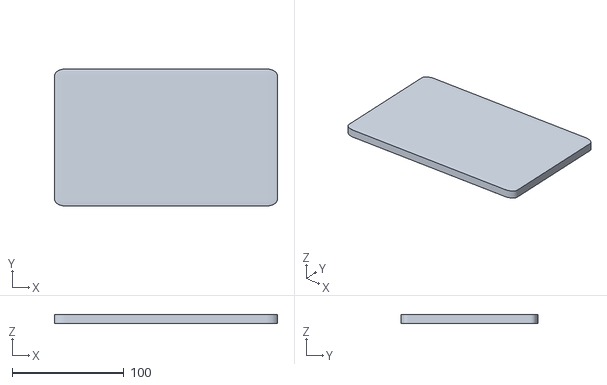
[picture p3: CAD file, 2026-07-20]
handoff/friend-rebuild-test/assets/tinker.obj
200.0 x 123.0 x 8.40

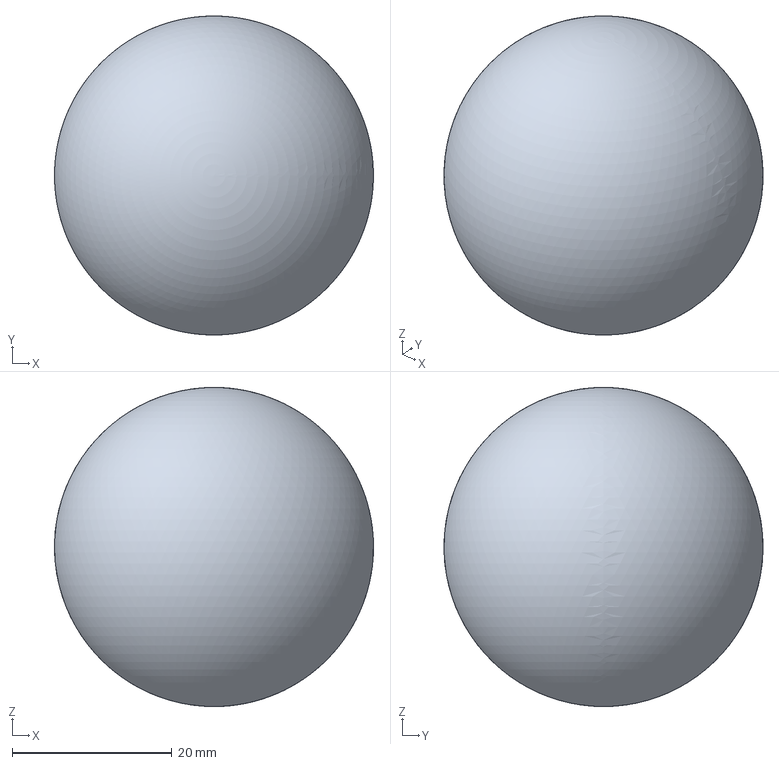
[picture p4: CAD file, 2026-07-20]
sphere_test.3mf
40.0 x 40.0 x 40.0 mm

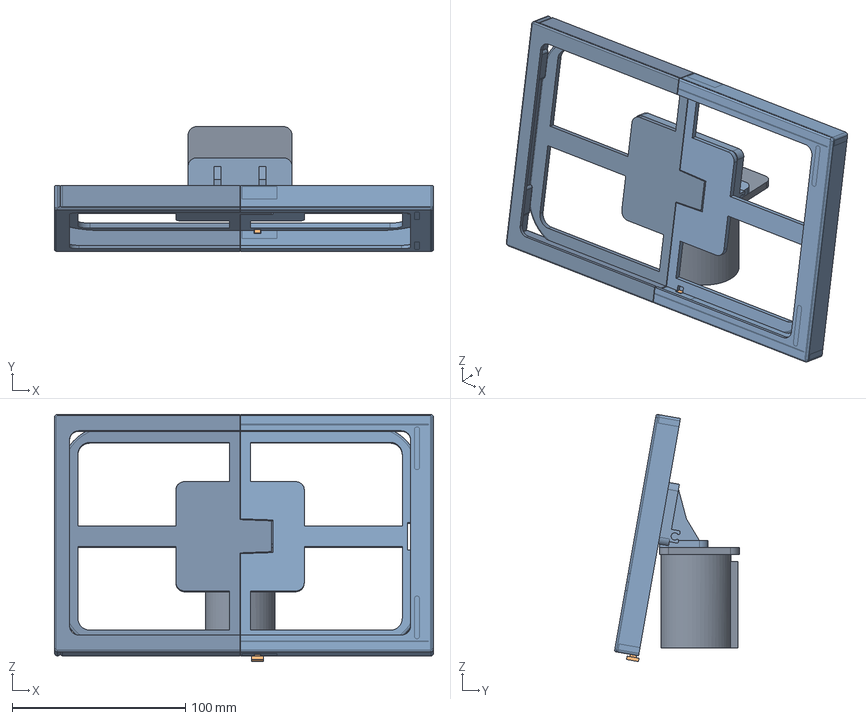
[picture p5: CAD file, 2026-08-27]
build/v3/tablet_stand_v3.step
218.5 x 72.0 x 142.5 mm
cradle_left
cradle_right
rear_bracket
sleeve
removable_locking_wedge

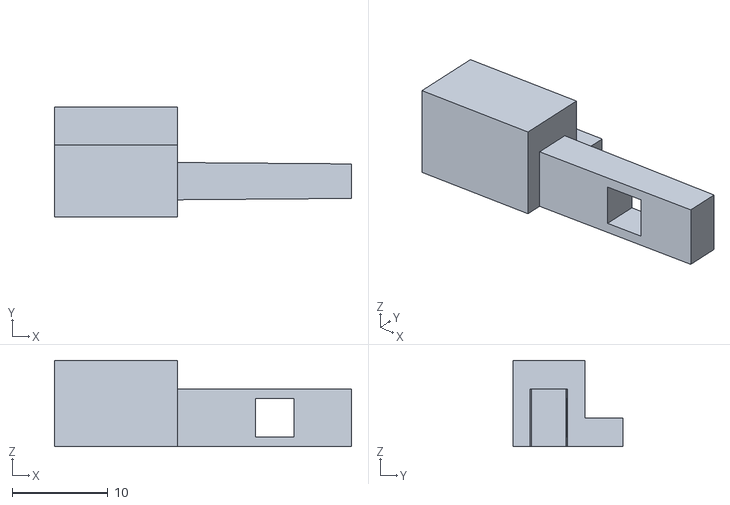
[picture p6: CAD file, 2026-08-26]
build/v3/tablet_stand_v3_lock_coupon_left.stl
31.0 x 11.5 x 9.00

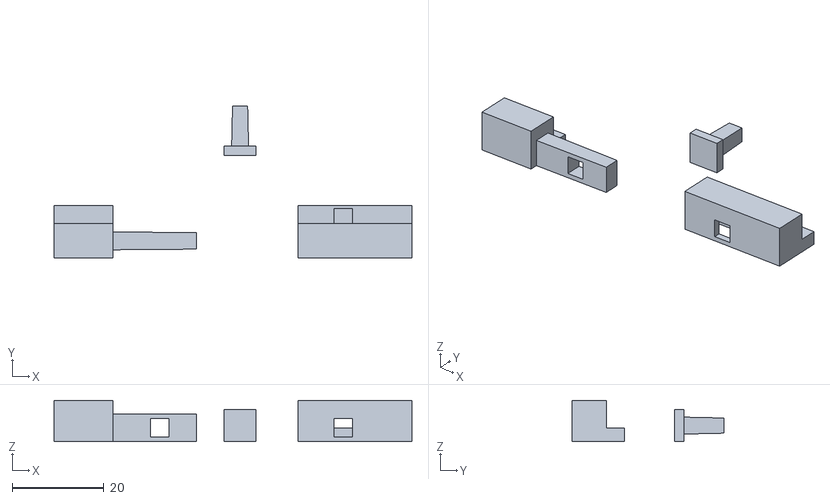
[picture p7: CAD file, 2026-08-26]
build/v3/tablet_stand_v3_lock_coupon_all3.stl
77.9 x 33.1 x 9.00

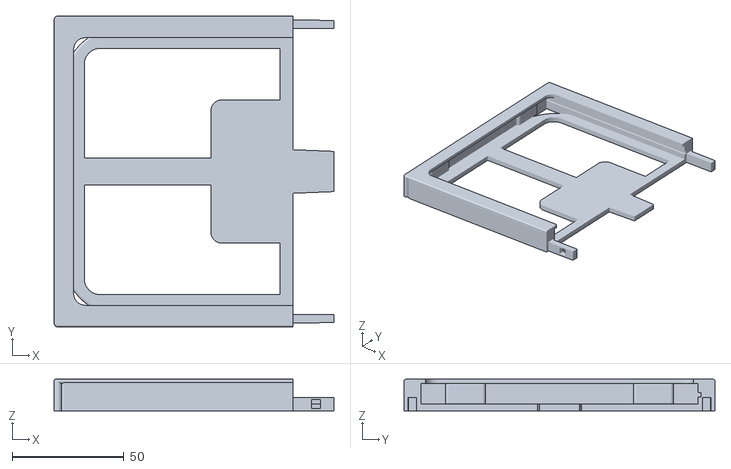
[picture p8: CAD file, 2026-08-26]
build/v3/tablet_stand_v3_cradle_left.stl
125.0 x 139.0 x 14.2

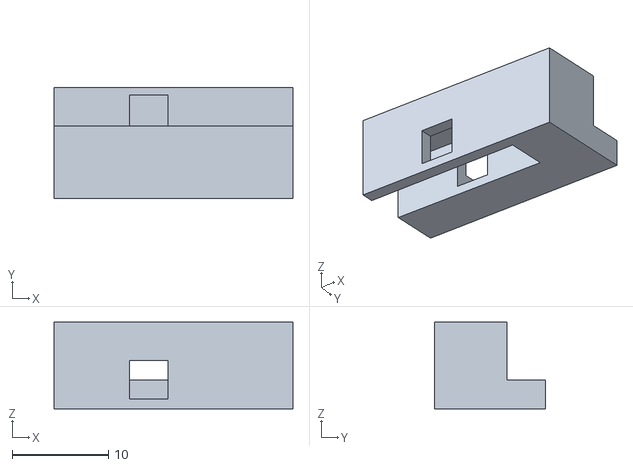
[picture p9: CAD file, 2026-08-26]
build/v3/tablet_stand_v3_lock_coupon_right.stl
24.8 x 11.5 x 9.00

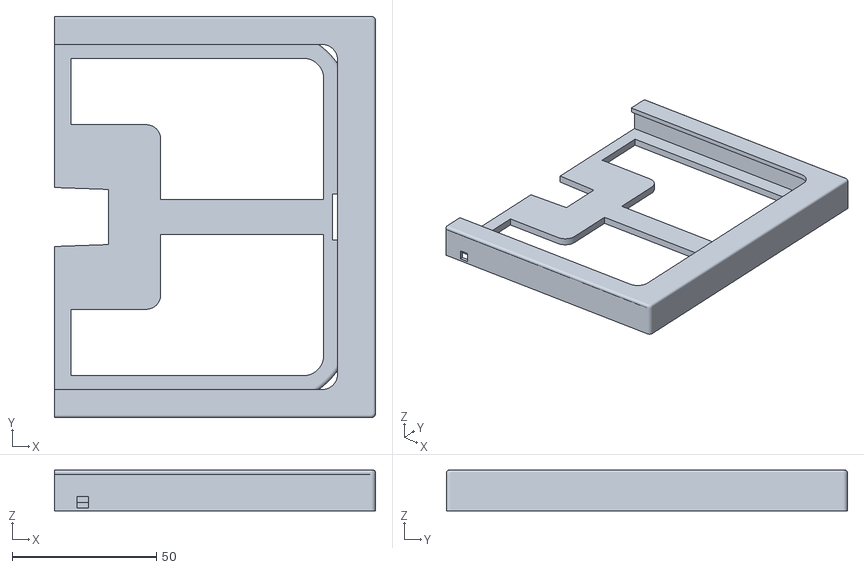
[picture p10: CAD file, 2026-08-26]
build/v3/tablet_stand_v3_cradle_right.stl
111.3 x 139.0 x 14.2

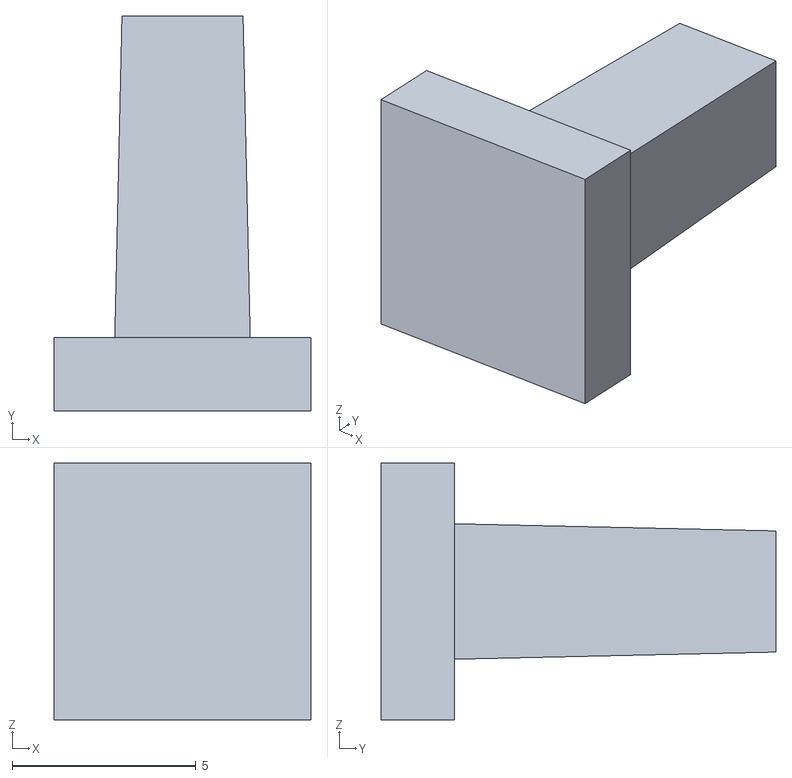
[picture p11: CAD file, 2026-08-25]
build/v3/tablet_stand_v3_locking_wedge.stl
7.00 x 10.8 x 7.00

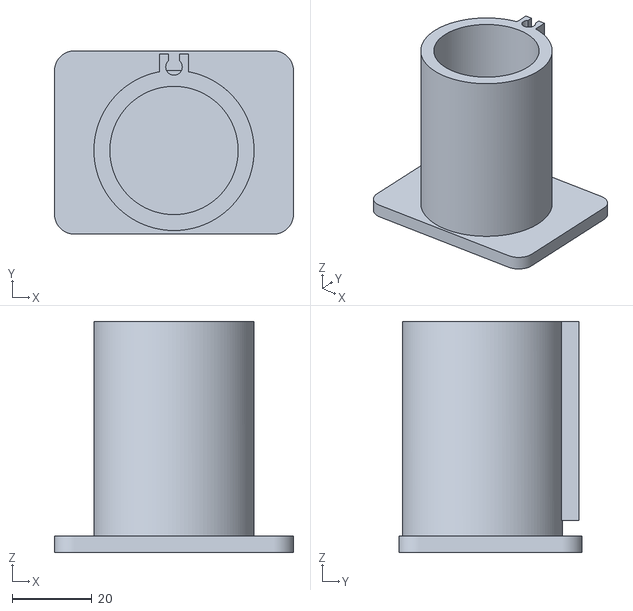
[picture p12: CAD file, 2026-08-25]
build/v3/tablet_stand_v3_sleeve.stl
60.0 x 46.0 x 58.0

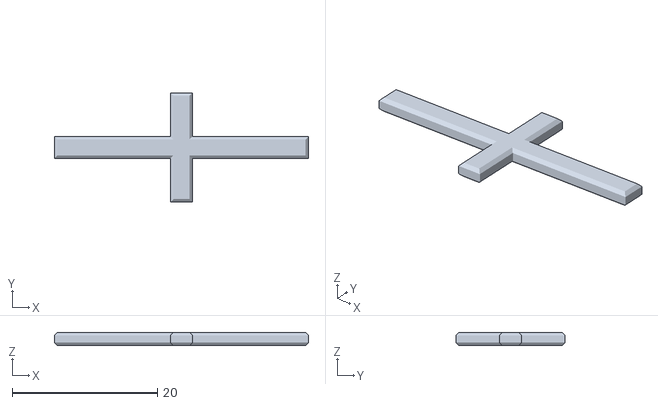
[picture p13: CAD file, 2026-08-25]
build/v3/tablet_stand_v3_alignment_key_print_1.stl
35.0 x 15.0 x 1.80

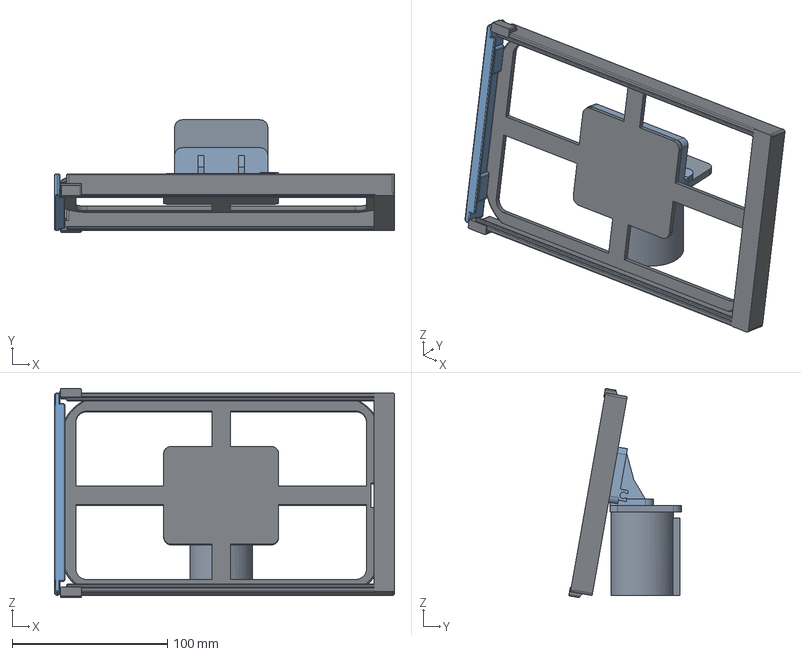
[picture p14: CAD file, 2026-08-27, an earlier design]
build/v2/tablet_stand_v2.step
218.8 x 72.4 x 134.7 mm
cradle
rear_bracket
sleeve
slide_end_stop
cradle_alignment_key
sleeve_alignment_key

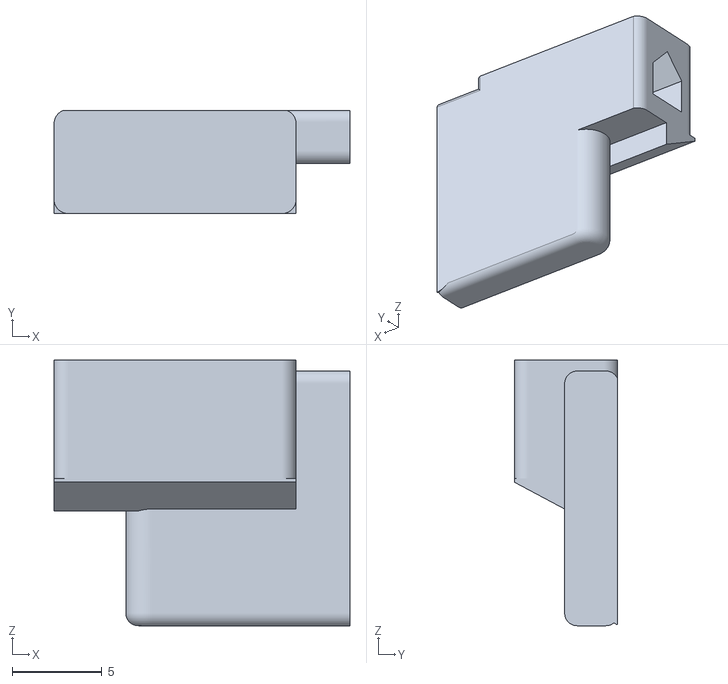
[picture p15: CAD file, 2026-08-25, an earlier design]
build/v2/tablet_stand_v2_left_slide_coupon_cradle.stl
16.5 x 5.75 x 14.8

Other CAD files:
build/v2/tablet_stand_v2_rear_bracket.stl
build/v2/tablet_stand_v2_right_fit_coupon.stl
build/v2/tablet_stand_v2_end_stop.stl
build/v2/tablet_stand_v2_button_fit_coupon.stl
build/v2/tablet_stand_v2_cradle.stl
build/v2/tablet_stand_v2_left_slide_coupon_plate.stl
build/v2/tablet_stand_v2_left_slide_coupon_stop.stl
build/v2/tablet_stand_v2_sleeve.stl
sphere_test.stl

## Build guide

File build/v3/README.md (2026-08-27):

# Version 3 removable split cradle

V3 preserves the physically tested tablet, button, USB-C, tube, and cable
interfaces. It replaces the 215 mm cradle and separate left cap with two
bed-friendly wings joined without cradle glue.

## Review files

- `tablet_stand_v3_multiview.png`: installed, enclosed-left-edge, USB/cable,
  removable-joint, and print-layout views of the smooth unified front ring.
- `tablet_stand_v3_preview.png`: installed assembly with the two wings in
  different blues and the locking wedge in orange.
- `tablet_stand_v3_left_edge.png`: continuous integral left wall with no
  obsolete end-stop/slider step.
- `tablet_stand_v3_button_channel.png`: inner-side detail of the full-travel
  concealed 2.0 × 1.2 mm left-wing button groove, highlighted in green.
- `tablet_stand_v3_rear_joint.png`: exploded view of the three tongues,
  receivers, and lower cross-wedge.
- `tablet_stand_v3_print_layout.png`: two independent rear-face-down wings and
  one locking wedge.
- `tablet_stand_v3_assembly_grooves.png`: annotated view of the matching
  cross-grooves on the bracket foot and sleeve flange.
- `tablet_stand_v3_bracket_to_cradle_bond.png`: annotated unkeyed adhesive
  contact areas between the fixed right wing and rear bracket.
- `tablet_stand_v3_rear_bracket_print.png`: active broad-plate-down bracket
  orientation with its single 12 mm cable channel opening upward.
- `tablet_stand_v3.step`: installed assembly.

## Production-oriented exports

- `tablet_stand_v3_cradle_left.stl`: 125.00 × 139.00 × 14.20 mm; rear face
  down; includes the enclosed rounded left edge and all three tongues.
- `tablet_stand_v3_cradle_right.stl`: 111.33 × 139.00 × 14.20 mm; rear face
  down; includes the three matching receivers and lower locking channel.
- `tablet_stand_v3_locking_wedge.stl`: print one; removable tapered cross-lock.
- `tablet_stand_v3_rear_bracket.stl`: bonds only to the fixed right wing;
  exported broad cradle-bond plate down with the one 12 mm cable channel up.
- `tablet_stand_v3_sleeve.stl`: unchanged tested 32.2 mm sleeve.
- `tablet_stand_v3_alignment_key_print_1.stl`: print one for the unchanged
  rear-bracket-to-sleeve adhesive joint.

## Active replacement-bracket print

- `tablet_stand_v3_rear_bracket_clips_up_pla.gcode`: validated functional PLA
  slice; 0.20 mm layers, five walls, 40% grid infill, no supports, no brim.
- `tablet_stand_v3_rear_bracket_clips_up_pla.ini`: resolved slicer settings
  extracted from the generated G-code configuration block.
- `tablet_stand_v3_rear_bracket_clips_up_validation.txt`: clean bounds,
  temperature, flow, thumbnail, and Klipper-macro validation.
- `tablet_stand_v3_rear_bracket_clips_up_print_record.json`: hashes, settings,
  camera clearance evidence, upload/start result, and job status.

The user explicitly authorized this replacement print. A fresh camera snapshot
showed the complete bed empty, Moonraker accepted the start at 2026-08-27
04:48:05 UTC, and the printer reported the job in progress.

## Exact joint coupon

- `tablet_stand_v3_lock_coupon_left.stl`: production lower tongue crop.
- `tablet_stand_v3_lock_coupon_right.stl`: production lower receiver crop.
- `tablet_stand_v3_lock_coupon_wedge.stl`: production locking wedge.
- `tablet_stand_v3_lock_coupon_all3.stl`: all three exact coupon parts spaced
  on one bed datum for the combined print job.
- `tablet_stand_v3_lock_coupon_plate.png`: direct CadQuery preview of that
  combined three-piece layout.

The first combined support-free plate was physically tested. Despite major
adhesion/stringing defects, the tongue and receiver fit together. The wedge
layout failed because its larger pull head put the narrower body about 1.65 mm
above the bed. Its stale combined G-code has been removed from the active tree;
give the wedge a common flat datum or removable support before any new print.

## Removable joint

The left wing slides +X. Its upper, center, and lower tongues enter 18 mm-deep
closed-back receivers. Seated/root clearance is 0.50 mm total; the tapered lead
has 1.10 mm total clearance.

The lower tongue and receiver have an aligned 4 × 4 mm transverse channel. A
printed wedge tapers from 3.70 to 3.30 mm and has a 7 mm pull head. If it proves
unreliable in the user's PLA, the same channel clears an M3 shaft; exact bolt,
washer, nut, and head pockets must wait for physical hardware measurements.

The rear bracket is glued only to the fixed right wing. Do not put adhesive on
the left wing, tongues, receivers, or wedge. Pulling the wedge and sliding the
left wing off must remain possible for tablet service.

The visible front perimeter is one continuous 2 mm ring across both wings,
with only the flush center split; separately stacked V2 lips, caps, bezel, and
coplanar shroud faces are gone. The concealed top-button groove runs from the
integral left closure-side interior to the center seam while retaining its
1.8 mm exterior wall.

Each individual-part STL export is a single watertight solid; the combined
three-piece lock-coupon plate intentionally contains three watertight components.
The pre-revision right-wing STL was sliced with snug 45° supports and a 5 mm brim,
independently validated, uploaded, and completed on 2026-08-10. The user
reported that the supports were difficult to distinguish/remove in this PLA.
The active rounded-finish geometry supersedes that G-code; all three stale
right-wing slices and their associated INI/print-record/validation files have
been removed from the active tree. Subsequent reprints should preserve the more
removable support strategy. On 2026-08-27 the user reported that all production
parts printed well and fit
great; permanent bracket/sleeve adhesive assembly remained to be completed.

## Historical coupon print evidence

- `tablet_stand_v3_lock_coupon_toolpath.png`: actual PrusaSlicer extrusion-path
  review from the physically tested combined job; it contains all three model
  islands and zero support extrusion.
- `tablet_stand_v3_lock_coupon_geometry.json` and
  `tablet_stand_v3_lock_coupon_brief.json`: inspected geometry and confirmed
  per-print decisions retained as fit evidence.

The user authorized and started that combined job on 2026-08-09. On 2026-08-10
the user reported major adhesion failure but confirmed that the tongue and
receiver still fit; the corrected wedge/pin then retained and released
successfully. The stale combined coupon G-code has been removed and remains
recoverable from Git history. Fresh full-part slices are now the next gate.

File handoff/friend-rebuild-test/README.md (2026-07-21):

# 2024 onn. 8-inch tablet stand — clean-room rebuild packet

This packet contains the original user-supplied reference assets, a selected set of the user's prompts reproduced verbatim, and a consolidated dimensions/requirements sheet.

The packet intentionally does **not** contain the existing stand CAD, generated previews, dimensions taken from that stand, or descriptions of how the current model was implemented. It is intended to let another designer make an independent solution from the original device, cable, mounting, and aesthetic requirements.

Start with:

1. `PROMPTS.md` — selected standalone prompts in the user's exact wording.
2. `DIMENSIONS-AND-REQUIREMENTS.md` — consolidated physical inputs, clarified requirements, conflicts, and unknowns.
3. `ASSET-MANIFEST.md` — provenance and checksums for every supplied asset.
4. `assets/` — the original OBJ/MTL and all three attached images.

Important: `codex-clipboard-17350a1e-0ddd-494b-af0b-a246416a2dfd.png` depicts an early 10°-above-horizontal interpretation that the user later superseded. The final requested orientation is kiosk-like: 10° back from vertical (80° above horizontal), with the top edge farther from the user than the bottom edge.

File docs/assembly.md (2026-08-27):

# V3 Assembly

## Cradle-to-bracket bond

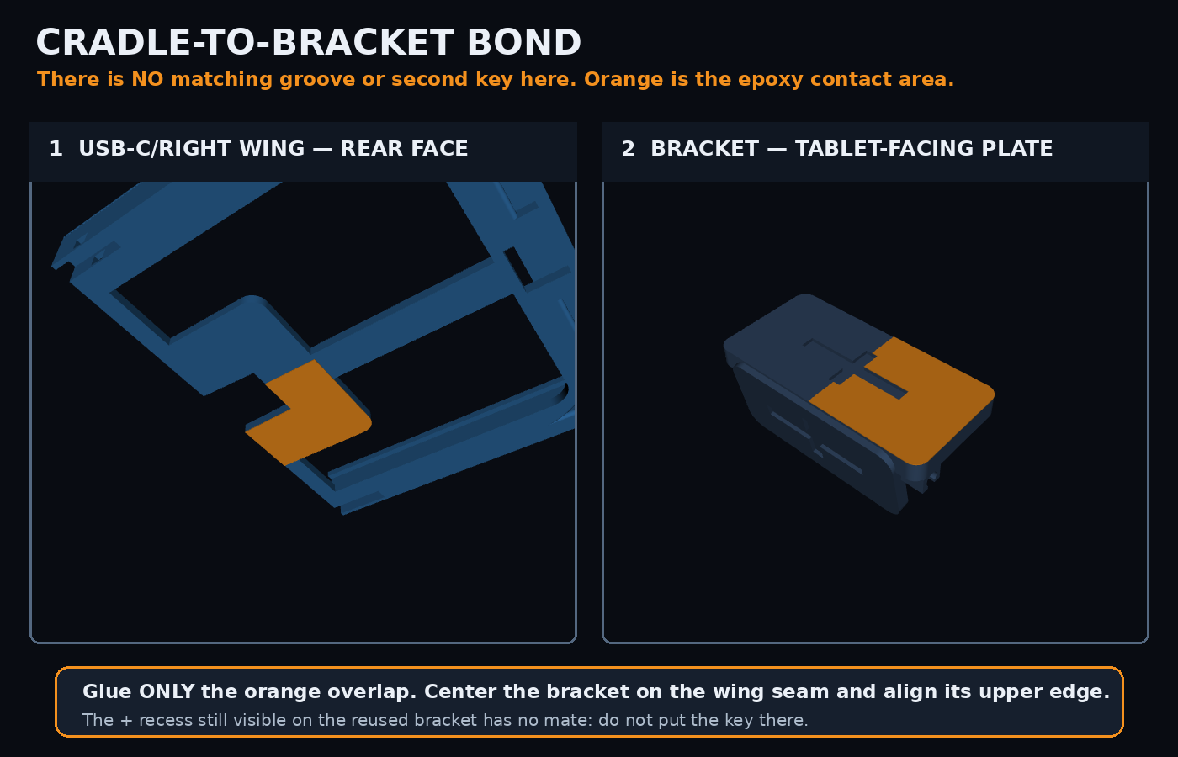
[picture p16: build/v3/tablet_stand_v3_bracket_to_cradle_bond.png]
Right-wing-to-bracket adhesive area


There is **no matching groove and no alignment key** between the cradle and bracket in V3. The reused bracket may still show its historical `+` recess, but the right wing intentionally has no matching recess. Do not put the printed key there.

Bond the orange contact areas shown above: the bracket's angled plate bonds only to the flat rear center plate of the fixed USB-C/right wing. Center the bracket on the wing seam and align its upper edge. Keep all adhesive off the removable left wing even though the bracket spans behind and may touch it.

## Bracket-to-sleeve keyed bond

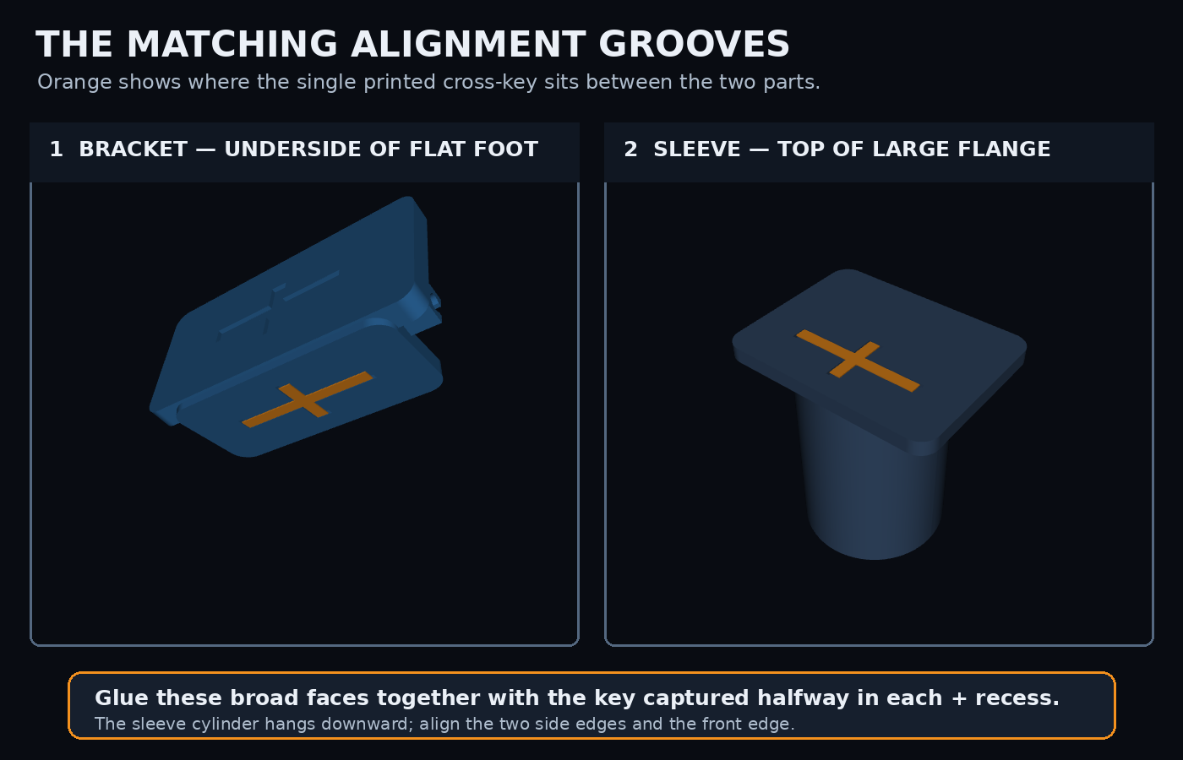
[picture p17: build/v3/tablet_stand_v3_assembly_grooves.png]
Bracket-to-sleeve alignment grooves


The cradle does not attach directly to the sleeve. The rear tilt bracket joins them.

1. Find the cross-shaped recess on the **underside of the bracket's 60 × 28 mm flat foot**.
2. Find the matching cross-shaped recess on the **top of the sleeve's 60 × 46 mm flange**. In the installed orientation, the sleeve cylinder hangs downward from this flange.
3. Dry-fit the single printed 35 × 15 × 1.8 mm cross-key between those recesses. It is intentionally loose: it aligns the parts while adhesive carries the finished joint.
4. Align the bracket foot with the sleeve flange's two side edges and front edge. The flange intentionally projects farther behind the bracket.
5. For PLA, lightly roughen the broad mating faces, clean them with isopropyl alcohol, and bond them with a thin layer of two-part epoxy. Keep adhesive out of the sleeve bore and cable channel. Clamp without distorting the parts and allow the adhesive's full labeled cure.
6. The separate cradle-to-bracket bond is the unkeyed joint shown at the top of this page.

Do not put adhesive on the tablet, removable left wing, tongues, receivers, locking wedge, sleeve bore, or cable channel.

If either printed mating face has no visible cross-shaped recess, stop rather than forcing the key; photograph both broad faces to determine whether first-layer fill or the wrong part orientation is hiding it.

## Loading the tablet

1. After both structural bonds have fully cured, slide the sleeve down over the accessible tube end.
2. Seat the tablet's USB-C/right edge in the fixed right wing.
3. Slide the enclosed left wing toward the right until all three tongues reach their closed receiver seats.
4. Insert the tapered cross-wedge through the lower transverse channel.
5. To remove the tablet, pull the wedge and slide the left wing away from the right wing.

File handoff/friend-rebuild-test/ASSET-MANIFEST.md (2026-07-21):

# Asset manifest

All files below are byte-for-byte copies of the user-supplied originals. SHA-256 values allow the recipient to verify that extraction or transfer did not alter them.

| File | Description | SHA-256 |
|---|---|---|
| `assets/tinker.obj` | User-supplied tablet reference mesh | `2c9b8806e64e52a87e7ebacec791b912b9a4fb774c618ab4b1893b57f28cefe8` |
| `assets/obj.mtl` | Material companion referenced by `tinker.obj` | `fcf8ac13a37b9b38b3052e32e8f2407ed103fb5f62b3468fe42578f922007f8b` |
| `assets/codex-clipboard-e3e4e085-fe62-40d4-a042-9b47d908e367.png` | Slim/right-angle USB-C product reference image attached to the initial prompt | `575f7f808ad992e87ae410be5e9742a2c2b65725099cb73130cf4a423226180e` |
| `assets/codex-clipboard-17350a1e-0ddd-494b-af0b-a246416a2dfd.png` | User-attached tilt discussion screenshot; depicts the superseded 10°-above-horizontal interpretation | `de3a6b13c21a19f52a0c6697288e47ec1d9f3da20c9b4bcc9ad1b73e86abc622` |
| `assets/IMG_7233 Large.jpeg` | User photo of the physical right-angle adapter/pigtail with handwritten measurements | `19ec9a4d504126cdbe89735f9cddd389249e7906bca843153358f7dcd3a62116` |

The ZIP does not contain any current stand CAD, generated stand STL/STEP, stand render, model parameter file, or implementation document.

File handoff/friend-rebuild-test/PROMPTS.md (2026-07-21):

# Selected original prompts

The text inside each fenced block is reproduced verbatim, including spelling, capitalization, punctuation, and measurement notation. Codex-generated attachment wrappers and local file paths are not part of the prompt text and are recorded separately in `ASSET-MANIFEST.md`.

Messages that only made sense in response to an intermediate model, preview, or prior assistant wording were omitted. Setup, Git, documentation, and tooling instructions were also omitted because they do not describe the object to be built. Their durable physical requirements are consolidated in `DIMENSIONS-AND-REQUIREMENTS.md` without exposing the existing CAD implementation.

## Prompt 1 — initial request

```text
Initialize proejct.  I want to design a 3d-printable tablet stand for my 2024 Onn 8" tablet.  Before jumping ton CAD rendering, let's just chat to make sure you understand what I want.  ASCII art rendering is good enough for now. Iy's goinh to  permanently sit on top of a 32mm OD tube - I've done some test prints and a 32.2mm ID cylinder wraps the tube perfectly tight.  then I want the table to rest at a 10o angle on top of that tube.  I'm not exactly sure how I want the tablet to be held regarding design but it should be enought material to be sturdy but not suffocate the tablet inside.  a front bezel would be cool but not required - talk to ne about tradeoffs.  likewise, if the table just sits in a tray stable enough to hold it, that's good enough, but if we want to wrap all sides, that's cool too.  Must have routing for a slim USB-C cable on the right hand side center of the tablet.  USBC cable is .7mm wide and flat and the slim connector to the tablet only sticks out 0.256mm deep. see image. also attaching a CAD rendering of the table for dimensions. for style I'm thinking simple and sleek.
```

Original attachments: `assets/tinker.obj`, `assets/obj.mtl`, and `assets/codex-clipboard-e3e4e085-fe62-40d4-a042-9b47d908e367.png`.

## Prompt 2 — final tilt correction

```text
Make sure to record all dimensions and decision as we go along. Remember this in is this project. 

Also looks like tablet is 10o angle from laying flat on a table (horizontal). I want it 10o angle cverticle almost like a kiosk
```

## Prompt 3 — corner treatment, insertion, and cable relief

```text
filet the outside corners a bit so it's not so sharp. Also I want the usb cable in the case and the tablet to slide into it.  I'm ok if it doesn't line up perfectly and I have to plug it in and then slide but the right hand side of the case should be closed with groove for usb cable to plug remember.  remember that the cable is flat at the end and only extends 0.256" from the tablet - it's very low profile
```

## Prompt 4 — physical right-angle cable photo

```text
 here's the end of the USB-C cable I have. I bought that right angle to wrap immediately around the back fo the tablet, exiting in a groove in/on the collet on the tube so it's largely hidden until it reaches the exit of the holder.
```

Original attachment: `assets/IMG_7233 Large.jpeg`.

## Prompt 5 — downstream cable construction

```text
after what you see in that pic it just convertes to a 3.45mm round braided wire.
```

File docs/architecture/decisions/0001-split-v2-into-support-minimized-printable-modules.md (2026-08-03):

# ADR-0001: Split V2 into support-minimized printable modules

- Status: superseded
- Date: 2026-07-28
- Deciders: Project maintainers
- Supersedes: None
- Superseded by: ADR-0002

## Context

The V1 main STL combines a tablet cradle tilted 80 degrees above horizontal,
a vertical closed tube sleeve, rear gussets, and cable clips. No single FDM
orientation serves all of those axes: printing the sleeve vertically leaves
the long cradle rails and sleeve seating-cap ceiling support-dependent, while
laying the cradle flat turns the fit-critical 32.2 mm bore nearly horizontal.
Support contact on the cradle rails can also consume the 0.5 mm-per-side tablet
clearance. The user requested a V2 optimized for a practical layout with
limited supports while preserving all confirmed tablet, tube, cable, and tilt
dimensions.

## Decision

V2 will be a four-part main assembly:

1. a cradle printed with its rear frame face on the bed;
2. a rear tilt bracket printed on a horizontal sleeve-interface foot;
3. a closed sleeve printed upside down on a flange, with the tube-entry bore
   open upward; and
4. the removable left end stop printed screen-lip face down.

The cradle and tilt bracket will use a broad adhesive bond indexed by matching
74 mm side edges and their shared top edge. The bracket foot and sleeve flange
will use a second broad adhesive bond indexed by matching 60 mm side edges and
their shared front edge. Both joints receive matching shallow cross grooves and
one identical printed alignment key; the key STL is printed twice. The tilt
bracket owns the two open braided-cable clips so the cradle can retain a flat
print face. The removable left end stop remains the only M3-fastened part. V1
remains preserved and reproducible.

## Consequences

### Positive

- The 32.2 mm sleeve bore prints vertically without internal support under its
  3 mm seating cap.
- The cradle's fit-critical long rails print vertically from a broad flat frame
  instead of against tall support towers.
- Support is limited to small bracket/clip details and short bridges that are
  accessible for cleanup.
- Each module can be reprinted independently after a fit change.
- The structural assembly does not depend on unconfirmed screw lengths, insert
  types, or nut access.
- The two keyed glue joints positively constrain X/Y alignment during cure.

### Negative

- Assembly adds two adhesive preparation, alignment, clamping, and cure steps.
- The physical assembly has six pieces because the alignment key is printed
  twice in addition to the four main modules.
- The bonded main-body joints are not intended for routine disassembly.
- Adhesive selection and surface preparation depend on the chosen filament.
- More parts and bonded interfaces create more tolerance stack-up than V1.
- V2 remains a concept until the end-stop fastener, controls, printer, material,
  adhesive, and fit coupons are physically verified.

## Alternatives considered

### Keep the monolithic V1 main part

Rejected because its best orientation still places roughly 7,700 mm2 of
downward-facing surface beyond a 45-degree support rule, including the
fit-critical upper rail and sleeve-cap ceiling.

### Lay the monolithic holder flat

Rejected because it makes the 51 mm sleeve nearly horizontal and introduces
support and distortion inside the user-tested 32.2 mm bore.

### Split only the cradle from an integrated sleeve-and-gusset pedestal

Rejected because the remaining pedestal still combines horizontal, vertical,
and tilted mounting faces without a broad support-free print datum.

## Verification

- `.venv/bin/python cad/tablet_stand_v2.py`
- `.venv/bin/python scripts/validate_model_v2.py`
- `.venv/bin/python scripts/render_cadquery_preview_v2.py`
- `build/v2/tablet_stand_v2_print_layout.png` visually shows every printable
  STL on its intended bed face, with the alignment-key STL printed twice.
- Validation requires one watertight connected component per STL, preserves the
  32.2 mm bore and 51 mm engagement, verifies both keyed glue joints and the
  single M3 end-stop alignment, and rejects installed part interference.

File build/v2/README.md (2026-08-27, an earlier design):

# Version 2 outputs

V2 is retained as the historical geometry basis and fit-coupon evidence while
V3 is the active removable-wing design.

## Print files

- `tablet_stand_v2_cradle.stl`: print rear frame face down.
- `tablet_stand_v2_rear_bracket.stl`: print the horizontal foot down.
- `tablet_stand_v2_sleeve.stl`: print the 60 × 46 mm flange down, with the
  32.2 mm tube-entry bore open upward.
- `tablet_stand_v2_end_stop.stl`: print its broad outside wall face down so the
  two tapered rail plugs build vertically. The cap slides horizontally into
  the cradle's reinforced open-ended rail sockets with no screw, hook, detent,
  projecting lower nub, or support-trapping dovetail.
- `tablet_stand_v2_alignment_key_print_2.stl`: print **two copies** flat.
- `tablet_stand_v2_right_fit_coupon.stl`: print rear face down before the full
  cradle; it is an exact 33.5 mm-wide crop of the production right end and
  tests the restored production rail allowances, right-edge stops, USB-C
  pocket, and the open 16 mm-wide × 8 mm-deep cable rectangle.
- `tablet_stand_v2_button_fit_coupon.stl`: print rear face down before the full
  cradle; it is an exact 73.5 × 11 × 14.8 mm crop of the production top-left
  rail. Slide it along the landscape-top tablet edge to verify that the
  measured 20–60 mm button group passes freely through the concealed 2 mm-high
  × 1.2 mm-deep inner groove without being pressed. The groove begins at the
  insertion end, extends 5 mm beyond the seated button group, and preserves a
  solid 1.8 mm exterior rail wall.
- `tablet_stand_v2_left_slide_coupon_cradle.stl` and
  `tablet_stand_v2_left_slide_coupon_stop.stl`: exact production crops of one
  rail socket and its identical tapered plug. Print them as separate jobs to
  check horizontal insertion, closed-end seating, retention, and real PLA
  clearance. `tablet_stand_v2_left_slide_coupon_plate.stl` is preview-only.
- `tablet_stand_v2_left_slide_coupon_cradle_rev2_pla.gcode` and
  `tablet_stand_v2_left_slide_coupon_stop_rev3_pla.gcode` are retained only as
  evidence for the physically tested V2 socket/plug process. The joint is not
  present in V3; do not use these files for the active holder.
- `tablet_stand_v2_left_slide_coupon_plate_preview.png`: six-view mesh review
  of the separated two-piece coupon plate in its corrected print orientations.
- Stale button-coupon, right-fit-coupon, two-key, full-cradle, and cap G-code
  is intentionally absent. The current V2 coupon STLs and all historical
  slices remain recoverable from Git history; regenerate from the current STL
  only if a new physical test is explicitly authorized.

`tablet_stand_v2.step` is the installed assembly. `model_parameters.json`
records the module orientations, glue joints, key dimensions, and preserved
fit-critical values.

## Alignment and assembly

Each structural glue joint uses one loose-fit 35 × 15 × 1.8 mm cross key. The
mating parts retain 36.25 × 16.25 × 4.25 mm cross grooves that are 1.15 mm deep
per side, leaving at least 1.25 mm total planar clearance and 0.50 mm total
thickness clearance for adhesive and print variation.

1. Bond the rear bracket plate to the cradle. Match the bracket's 74 mm side
   edges and top edge to the cradle center plate.
2. Bond the bracket foot to the sleeve flange. Match the 60 mm side edges and
   front edges.
3. Keep adhesive out of the tablet cavity, tube bore, cable features, and
   removable end-stop path.
4. Clamp each joint against a flat reference until fully cured.

Choose adhesive for the printed material: two-part epoxy is the conservative
general choice; use a plastic-specific adhesive for PETG and roughen/clean both
bond faces according to the adhesive instructions.

## Printability

All five production STL files and four individual fit-coupon part STLs are
single watertight solids. The combined left-slide coupon plate intentionally
contains those two watertight pieces. The alignment-key STL is printed twice.
The cradle has a broad 215 × 135.6 mm rear datum, the bracket has a 60 × 28 mm foot, and the
sleeve has a 60 × 46 mm flange. The modular split avoids tall rail-support
towers and the support ceiling inside the sleeve bore.
The remaining flagged overhangs are predominantly the cradle's 2.2 mm lips,
short USB-C bridges, shallow alignment-groove roofs, and the one 12 mm open
cable channel.

Start with no supports at 0.20 mm layers and inspect the slicer preview. The
active V3 replacement bracket supersedes this historical foot-down orientation:
it prints broad cradle-bond plate down with its cable-channel opening upward.
The cradle cannot be rotated diagonally into a smaller bounding box.
The production plate removes the optional 6 mm skirt and centers the 215 mm
cradle. Do not add a skirt or brim to this job. Test the twin-plug coupon before
uploading the full cradle.

V2 is a validated concept, not a production-ready release. Confirm the remaining
device clearances, physical twin-plug coupon result, tube length, adhesive
choice, and other fit coupons before a full print.

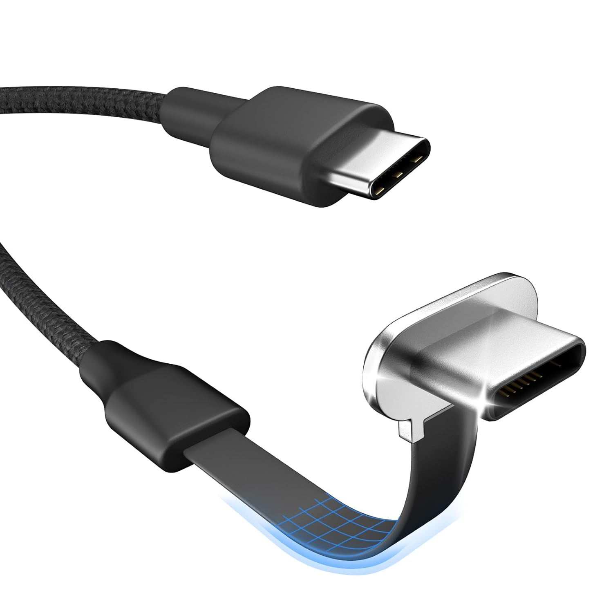
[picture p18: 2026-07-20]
handoff/friend-rebuild-test/assets/codex-clipboard-e3e4e085-fe62-40d4-a042-9b47d908e367.png

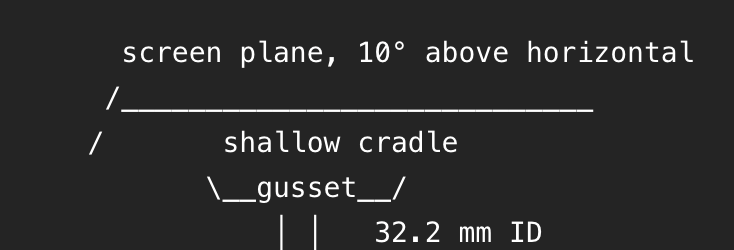
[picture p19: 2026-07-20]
handoff/friend-rebuild-test/assets/codex-clipboard-17350a1e-0ddd-494b-af0b-a246416a2dfd.png

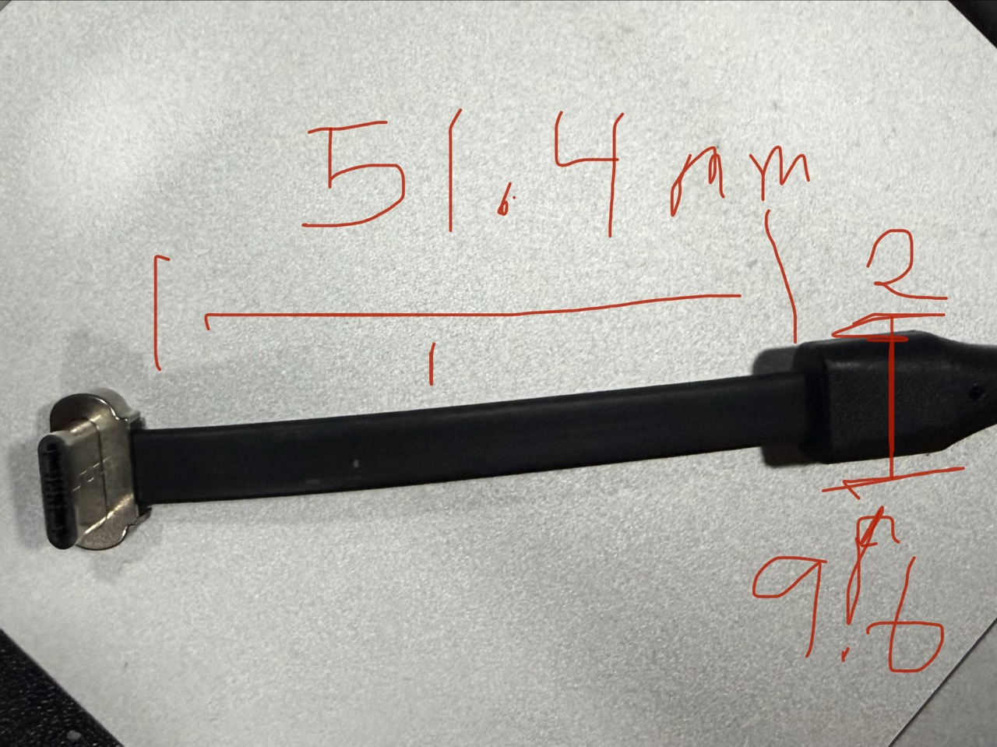
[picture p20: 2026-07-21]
handoff/friend-rebuild-test/assets/IMG_7233 Large.jpeg

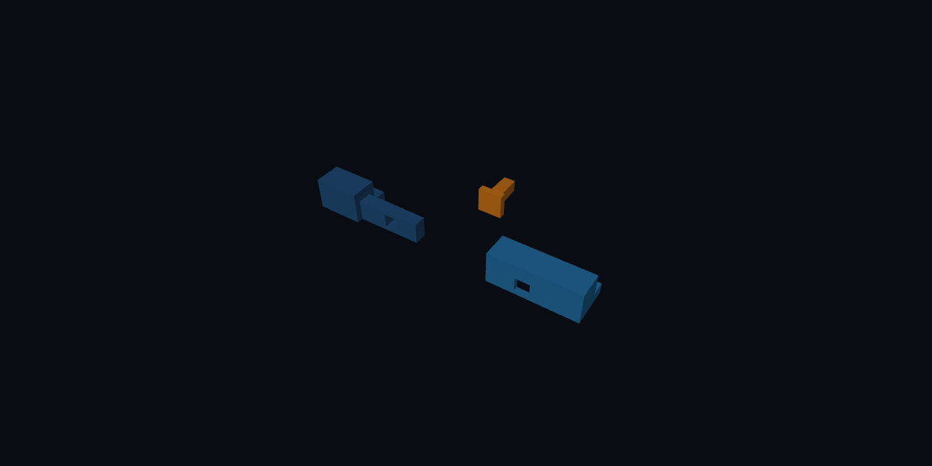
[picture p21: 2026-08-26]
build/v3/tablet_stand_v3_lock_coupon_plate.png

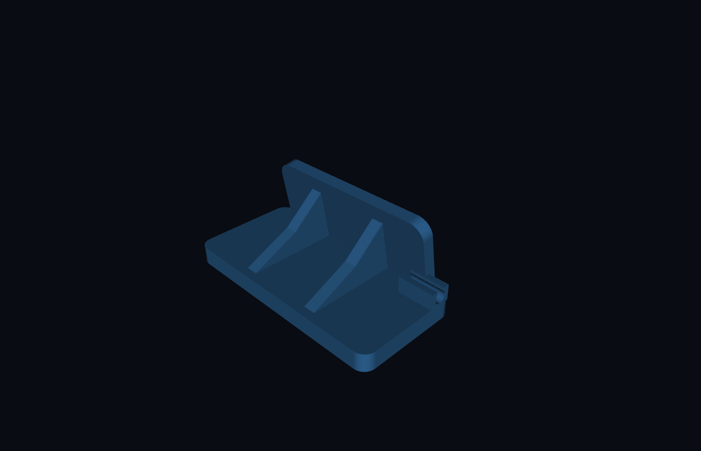
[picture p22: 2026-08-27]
build/v3/tablet_stand_v3_rear_bracket_print.png

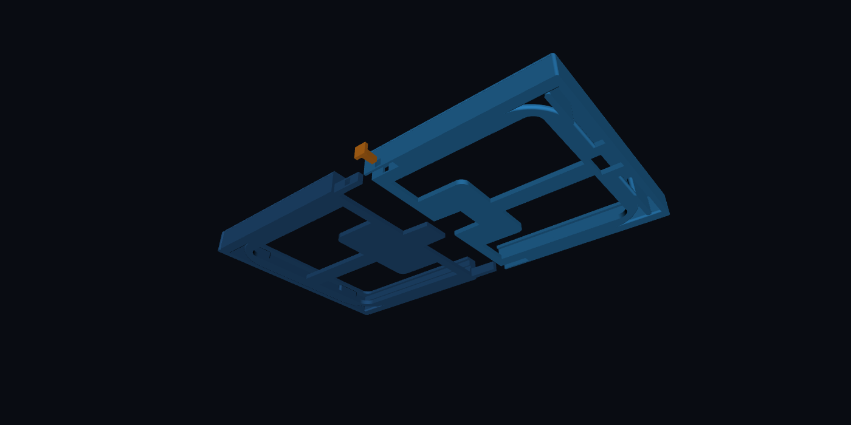
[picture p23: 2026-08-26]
build/v3/tablet_stand_v3_rear_joint.png

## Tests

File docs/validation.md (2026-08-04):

# Build and Validation

Run the following after any CAD or rendering change. The root [`AGENTS.md`](../AGENTS.md) requires the `3d-model` skill before performing such work.

```bash
.venv/bin/python cad/tablet_stand_v2.py
.venv/bin/python scripts/validate_model_v2.py
.venv/bin/python scripts/render_cadquery_preview_v2.py
```

These commands regenerate the active STEP, production and coupon STL files, parameter JSON, installed preview, rear detail, print layout, and multiview sheets. Validation checks the kiosk angle, tablet and button clearances, USB-C route, clear 32.2 mm tube path, 51 mm engagement, solid seating cap, flat print datums, adhesive-joint groove alignment, two-copy cross key, both screw-free tapered rail plugs and sockets, closed seating ends, root/tip clearances, minimum receiver walls, collision-free horizontal insertion travel, required files, and one watertight component per STL. The preview script renders directly from in-memory CadQuery tessellation; it does not import an STL.

On a headless macOS session, set `CAD_PREVIEW_HEADLESS=1` for the preview command. This uses the VTK depth-buffered fallback while preserving direct in-memory CadQuery tessellation.

Before marking a revision print-ready, visually inspect the generated previews, confirm every requested feature remains visible, and test-slice every manufacturing STL in its documented orientation. A full V2 print also requires physical fit coupons for the rail clearance, end stop, tube sleeve, cable route, and glue-joint alignment key, plus an adhesive test using the selected filament.

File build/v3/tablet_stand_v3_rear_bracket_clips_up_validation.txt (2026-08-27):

build/v3/tablet_stand_v3_rear_bracket_clips_up_pla.gcode  (63648 lines, 45582 extruding moves)
checked against: Creality Ender-3 Pro -- 220.0x220.0x250.0mm, 0.4mm nozzle, 1.75mm filament, cartesian_bedslinger, klipper, direct extruder, 10.0 mm3/s PLA, accel 1500.0 (untuned)

  [ok] Peak flow 7.5 mm3/s, within the 10.0 ceiling.
  [ok] Footprint X 67-153, Y 85-133, Z to 28.6mm -- inside the build volume.
  [ok] Nozzle temps [210.0]C -- reasonable for PLA.
  [ok] No M104/M140 for the bed, but START_PRINT receives it as a parameter -- this is the correct pattern and avoids a double heat cycle.
  [ok] Thumbnails present (10KB of base64).
  [ok] No M73 progress reporting -- optional, but it gives Klipper a remaining-time estimate.
  [ok] Estimated time: 1h 31m 33s. Filament: ~22.4g (7.5m extruded).
  [ok] Produced by: generated by PrusaSlicer 2.8.1+linux-x64-GTK3 on 2026-08-27 at 04:43:54 UTC

Clean. Ready to print.

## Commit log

2026-07-20 Initialize tablet stand project
    [sphere_test.3mf, sphere_test.stl, tinker.obj]
2026-07-20 Add first tablet stand CAD concept
    [tablet_stand_end_stop.stl, tablet_stand_end_stop_installed.stl, tablet_stand_main.stl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]
2026-07-20 Correct stand to kiosk viewing angle
    [tablet_stand_end_stop_installed.stl, tablet_stand_main.stl, tablet_stand_v1.step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]
2026-07-21 Document persistent CAD workflow
2026-07-21 Enclose USB-C cable pocket and soften holder corners
    [tablet_stand_end_stop.stl, tablet_stand_end_stop_installed.stl, tablet_stand_main.stl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]
2026-07-21 Record rear-hidden USB-C cable route
2026-07-21 Route braided USB-C cable through rear sleeve channel
    [tablet_stand_main.stl, tablet_stand_v1.step]
2026-07-21 Lower rear sleeve to holder bottom
    [tablet_stand_main.stl, tablet_stand_v1.step]
2026-07-21 Replace cable channel with wide pass holes
    [tablet_stand_main.stl, tablet_stand_v1.step]
2026-07-21 Restore cable clips and route around solids
    [tablet_stand_main.stl, tablet_stand_v1.step]
2026-07-21 Add clean-room rebuild handoff packet
    [tinker.obj]
2026-07-22 Enclose tablet holder right side
    [tablet_stand_main.stl, tablet_stand_v1.step]
2026-07-28 Add support-minimized modular tablet stand v2
    [tablet_stand_v1.step, tablet_stand_v2.step, tablet_stand_v2_alignment_key_print_2.stl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]
2026-07-31 Add validated rear bracket G-code
2026-08-01 Loosen V2 glue alignment keys
    [tablet_stand_v2.step, tablet_stand_v2_alignment_key_print_2.stl]
2026-08-01 Check printer camera before bed-clear prompt
2026-08-02 Add right-side tablet fit coupon
    [tablet_stand_v2.step, tablet_stand_v2_right_fit_coupon.stl]
2026-08-02 Open USB-C cable notch from fit test
    [tablet_stand_main.stl, tablet_stand_v1.step, tablet_stand_v2.step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]
2026-08-02 Tighten tablet rail fit from physical test
    [tablet_stand_end_stop.stl, tablet_stand_end_stop_installed.stl, tablet_stand_main.stl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]
2026-08-02 Restore rail fit and simplify cable opening
    [tablet_stand_end_stop.stl, tablet_stand_end_stop_installed.stl, tablet_stand_main.stl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]
2026-08-02 Add measured button clearance channel
    [tablet_stand_main.stl, tablet_stand_v1.step, tablet_stand_v2.step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]
2026-08-03 Conceal button relief inside top rail
    [tablet_stand_main.stl, tablet_stand_v1.step, tablet_stand_v2.step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]
2026-08-03 Archive V1 and prepare cradle slice review
    [tablet_stand_end_stop.stl, tablet_stand_end_stop_installed.stl, tablet_stand_main.stl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]
2026-08-03 Replace M3 stop with friction slide
    [tablet_stand_v2.step, tablet_stand_v2_button_fit_coupon.stl, tablet_stand_v2_cradle.stl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]
2026-08-03 Refine left stop into captured dovetail
    [tablet_stand_v2.step, tablet_stand_v2_button_fit_coupon.stl, tablet_stand_v2_cradle.stl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]
2026-08-03 Make dovetail coupon printable with difficult PLA
    [tablet_stand_v2.step, tablet_stand_v2_button_fit_coupon.stl, tablet_stand_v2_cradle.stl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]
2026-08-03 Record supported coupon print start
2026-08-04 Replace dovetail stop with twin tapered rail plugs
    [tablet_stand_v2.step, tablet_stand_v2_button_fit_coupon.stl, tablet_stand_v2_cradle.stl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]
2026-08-06 Loosen and strengthen twin plug fit
    [tablet_stand_v2.step, tablet_stand_v2_button_fit_coupon.stl, tablet_stand_v2_cradle.stl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]
2026-08-06 Fine tune plug clearance after socket fit test
    [tablet_stand_v2.step, tablet_stand_v2_button_fit_coupon.stl, tablet_stand_v2_cradle.stl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]
2026-08-10 Add split-cradle V3 with integral left wing
    [tablet_stand_v3.step, tablet_stand_v3_alignment_key_print_2.stl, tablet_stand_v3_cradle_left.stl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]
2026-08-10 Replace V3 glue seam with removable tongue lock
    [tablet_stand_v3.step, tablet_stand_v3_alignment_key_print_1.stl, tablet_stand_v3_cradle_left.stl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]
2026-08-10 Prepare and start V3 lock coupon print
    [tablet_stand_v3.step, tablet_stand_v3_cradle_left.stl, tablet_stand_v3_cradle_right.stl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]
2026-08-10 Record V3 coupon fit and wedge print failure
2026-08-10 Start validated right cradle wing print
2026-08-11 Record right-wing support removal feedback
2026-08-11 Round V3 frame corners and preserve alignment key
    [tablet_stand_v2.step, tablet_stand_v2_button_fit_coupon.stl, tablet_stand_v2_cradle.stl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]
2026-08-11 Smooth V3 front perimeter around rear joiners
    [tablet_stand_v2.step, tablet_stand_v2_button_fit_coupon.stl, tablet_stand_v2_cradle.stl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]
2026-08-11 Close V3 left outer wall
    [tablet_stand_v2.step, tablet_stand_v2_button_fit_coupon.stl, tablet_stand_v2_cradle.stl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]
2026-08-11 Start revised right-wing fit print
2026-08-11 Extend V3 right closure to full perimeter
    [tablet_stand_v3.step, tablet_stand_v3_cradle_left.stl, tablet_stand_v3_cradle_right.stl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]
2026-08-25 Prepare corrected right-wing PLA slice
2026-08-25 Curve V3 front opening over tablet corners
    [tablet_stand_v3.step, tablet_stand_v3_cradle_left.stl, tablet_stand_v3_cradle_right.stl]
2026-08-25 Shift USB rear opening inboard
    [tablet_stand_v2.step, tablet_stand_v2_alignment_key_print_2.stl, tablet_stand_v2_button_fit_coupon.stl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]
2026-08-25 Enlarge USB rear opening inboard
    [tablet_stand_v2.step, tablet_stand_v2_button_fit_coupon.stl, tablet_stand_v2_cradle.stl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]
2026-08-25 Round V3 exterior frame edges
    [tablet_stand_v2.step, tablet_stand_v2_button_fit_coupon.stl, tablet_stand_v2_cradle.stl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]
2026-08-25 Remove obsolete generated print artifacts
2026-08-26 Unify V3 visible frame and button slide channel
    [tablet_stand_v3.step, tablet_stand_v3_cradle_left.stl, tablet_stand_v3_cradle_right.stl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]
2026-08-26 Clarify V3 STL component documentation
2026-08-27 Add illustrated V3 assembly guide
2026-08-27 Clarify unkeyed cradle bracket bond
2026-08-27 Replace rear clips and print bracket channel-up
    [tablet_stand_v2.step, tablet_stand_v2_rear_bracket.stl, tablet_stand_v3.step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]
